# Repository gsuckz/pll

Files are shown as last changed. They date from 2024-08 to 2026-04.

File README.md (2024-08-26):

# Sintetizador de Frecuencias en banda Ku 

## Funcionamiento
    El dispositivo genera una señal en banda Ku {10,6 , 11,8} GHz. Con un paso de 1Mhz, teniendo 1200 Valores posibles. Estos se envían a través de una aplicacion de Android usando Bluetooth. También es posible realizar un barrido de frecuecnias, con un paso menor, 0,25 MHz.

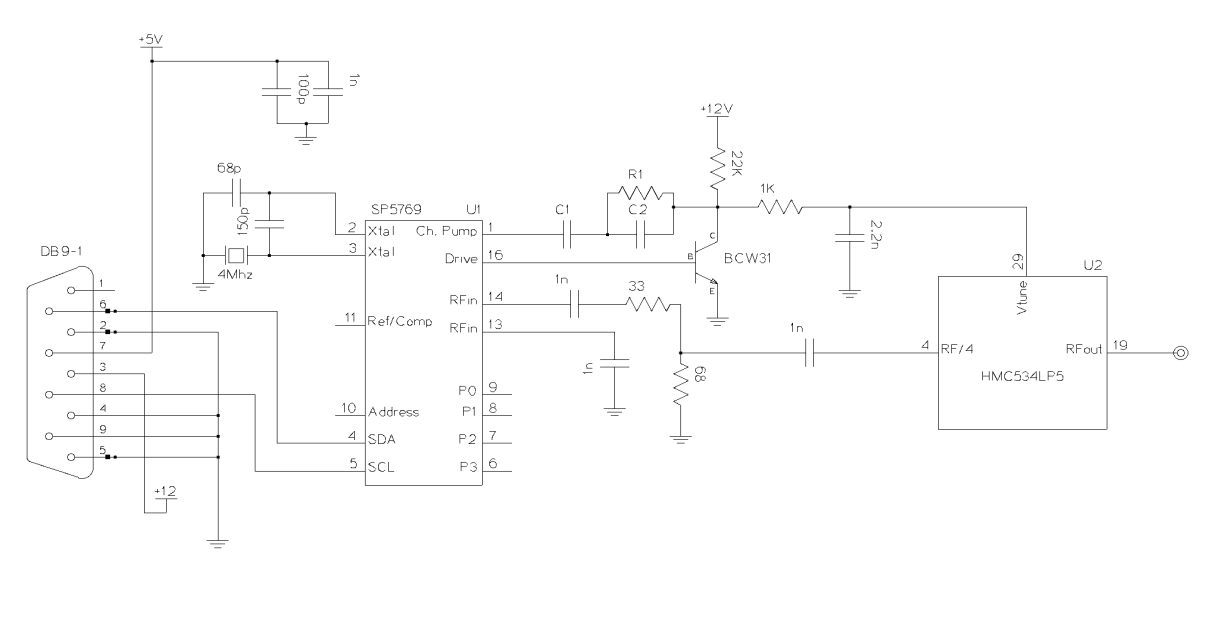
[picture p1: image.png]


Este repositorio contiene el código para controlar un Sintentizador de frecuencias Zarlink SP5769 que controla un VCO HMC534LP5.

La dirección I2C del SP5769 se selecciona con el nivel del tension aplicado a ADDRESS (%Vcc) ADDRESS = "11000101"

El ESP32 debe escribir en los registros del SP5769 los valores (a través de un bus I2C). Los registros son:
## Programmable divider: 
    Controla la razón entre la frecuencia del VCO interno y la de referencia (Un numero de 15 bit)
## Control Data: Tiene varios bits que controlan el funcionamiento (Ver datasheet para saber posicion):

    [R3:R0]: Controla el divisor de frecuencia de referencia (Ver tabla) - Ajustado al valor 64 -> 0101

    [C1:C0]: Seleccion la corriente de la bomba de carga. Ver tabla datasheet (Valor fijado por el circuito)

    RE: Enable del oscilador de ref 

    [T2:T0] = Bits de control de modo test - No se usa

    [P3:P0] = Estados del puerto de salida - No se usa

    RS: REF/COMP seleccion (Se usa alta impedancia)

Aquí se configura: Modo Test Off, Corriente de la bomba de carga Icp=+-155[µA], pin
de REF/COMP en alta impedancia, y todos los puertos, P3 a P0 a 0[V]

## Especifaciones del programa 
### Iniciar 
    El programa debe iniciar la comunicación por bluetooth y configurar el registro de control según se indica en el documento "INFORME-TRABAJO-GRADUACION-CANGEMI-JOSE-I.pdf". Luego debe esperar por cualquiera de las 2 instrucciones posibles.

### Ajuste de frecuencia
    El programa debe recibir por bluetooth el valor de la frecuncia deseada, luego debe calcular el valor del multiplicador necesario y escribirlo en los registros programmable divider.

### Barrido de frecuencia
    El programa de barrer las frecuencias sintetizables en un tiempo indicado por el usuario. Con limites Tmin y Tmax

El valor recibido es una cadena de caracteres con la frecuencia

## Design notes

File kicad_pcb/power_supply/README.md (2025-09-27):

## Datasheet Componentes
- VCO HMC534LP5: [Datasheet](https://www.analog.com/media/en/technical-documentation/data-sheets/hmc534.pdf)

- Sintetizador SP5769: [Datasheet](https://www.alldatasheet.com/datasheet-pdf/view/77217/MITEL/SP5769.html)

- Diodo Zener 1N4732A (4.7V): [Datasheet](https://www.alldatasheet.com/datasheet-pdf/view/58834/DIODES/1N4733A.html) 

- Diodo Zener BZX55C12 (12V): [Datasheet](https://www.vishay.com/docs/85604/bzx55.pdf)

- Tiristor MCR100-6 : [Dataset](https://www.alldatasheet.com/datasheet-pdf/view/888541/SEMTECH_ELEC/MCR100-6.html)

- Tiristor TYN615 (SCR): [Datasheet](https://www.alldatasheet.es/datasheet-pdf/view/25111/STMICROELECTRONICS/TYN612.html)

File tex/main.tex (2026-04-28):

% ============================================================
%  INFORME DE PRÁCTICA PROFESIONAL SUPERVISADA
%  Reparación y Rediseño de Sintetizador de Frecuencias Banda Ku
% ============================================================
\documentclass[12pt, a4paper]{article}

% --- Paquetes ---
\usepackage[spanish, es-tabla]{babel}
\usepackage[utf8]{inputenc}
\usepackage[T1]{fontenc}
\usepackage{geometry}
\geometry{top=2.5cm, bottom=2.5cm, left=3cm, right=2.5cm}

\usepackage{graphicx}
\usepackage{float}
\usepackage{booktabs}
\usepackage{array}
\usepackage{amsmath}
\usepackage{amssymb}
\usepackage{hyperref}
\usepackage{fancyhdr}
\usepackage{titlesec}
\usepackage{setspace}
\usepackage{parskip}
\usepackage{caption}
\usepackage{subcaption}
\usepackage{xcolor}
\usepackage{tcolorbox}
\usepackage{enumitem}
\usepackage{listings}
\usepackage{microtype}
\usepackage{lmodern}
\usepackage{pdfpages}

% --- Color institucional ---
\definecolor{azulUNT}{RGB}{0, 51, 102}
\definecolor{grisClaro}{RGB}{230, 230, 230}
% --- Encabezado y pie de página ---
\pagestyle{fancy}
\fancyhf{}
\fancyhead[L]{\small\textcolor{azulUNT}{PPS – Sintetizador de Frecuencias Banda Ku}}
\fancyhead[R]{\small\textcolor{azulUNT}{UNT – FCEyT}}
\fancyfoot[C]{\thepage}
\renewcommand{\headrulewidth}{0.4pt}

% --- Formato de títulos ---
\titleformat{\section}
{\large\bfseries\color{azulUNT}}
{\thesection.}{0.5em}{}[\titlerule]

\titleformat{\subsection}
{\normalsize\bfseries\color{azulUNT}}
{\thesubsection}{0.5em}{}

\titleformat{\subsubsection}
{\normalsize\itshape\bfseries}
{\thesubsubsection}{0.5em}{}

% --- Listings (código) ---
\lstset{
	basicstyle=\ttfamily\small,
	keywordstyle=\color{azulUNT}\bfseries,
	commentstyle=\color{gray}\itshape,
	stringstyle=\color{red!60!black},
	numbers=left,
	numberstyle=\tiny\color{gray},
	frame=single,
	breaklines=true,
	captionpos=b,
	language=C++
}

% --- Interlineado ---
\setstretch{1.15}

% ============================================================
\begin{document}
	
	% ============================================================
	%  PORTADA
	% ============================================================
	\thispagestyle{empty}
	\begin{titlepage}
		\centering
		\vspace*{0.5cm}
		
		{\Large \textbf{Universidad Nacional de Tucumán}}\\[0.3cm]
		{\large Facultad de Ciencias Exactas y Tecnología}\\[0.2cm]
		{\large Carrera: Ingeniería en Electrónica}\\[2cm]
		
		\noindent\rule{\textwidth}{1.5pt}\\[0.4cm]
		{\LARGE \textbf{Reparación y Rediseño de un\\[0.2cm]
				Sintetizador de Frecuencias en Banda Ku}}\\[0.3cm]
		\noindent\rule{\textwidth}{1.5pt}\\[1.5cm]
		
		{\large \textbf{Informe de Práctica Profesional Supervisada}}\\[2cm]
		
		\begin{minipage}[t]{0.48\textwidth}
			\raggedright
			\textbf{Autor:}\\
			Alexis Vale
			Jesús Avila
		\end{minipage}
		\hfill
		\begin{minipage}[t]{0.48\textwidth}
			\raggedleft
			\textbf{Directores:}\\
			Fernando Miranda Bonomi\\
			Juan Ise
		\end{minipage}\\[2cm]
		
		\textbf{Lugar de realización:}\\
		Laboratorio de Telecomunicaciones – FaCET – UNT\\[1cm]
		
		\textbf{Período:} 2025–2026\\[2cm]
		
		\vfill
		{\small Tucumán, Argentina}
	\end{titlepage}
	
	% ============================================================
	%  RESUMEN
	% ============================================================
	\newpage
	\thispagestyle{plain}
	\section*{Resumen}
	\addcontentsline{toc}{section}{Resumen}
	
	El presente informe describe el proceso de recuperación y rediseño integral de un sintetizador de
	frecuencias para microondas diseñado para operar en la banda Ku (10{,}6~GHz a 11{,}8~GHz),
	originalmente desarrollado en 2009 y recibido en estado no funcional. El trabajo abarcó el diagnóstico
	del hardware heredado, la identificación de fallas críticas en el oscilador controlado por tensión (VCO),
	el reemplazo de componentes dañados y, finalmente, el rediseño completo del circuito impreso (PCB)
	ante la degradación acumulada por múltiples intervenciones previas.
	
	Como parte del rediseño, el controlador original (microcontrolador PIC) fue reemplazado por una
	plataforma ESP32, incorporando comunicación Bluetooth e interfaz de usuario. La validación funcional
	se realizó en el banco de microondas del Laboratorio de Telecomunicaciones, confirmando el
	enclavamiento del lazo PLL con un error relativo menor al 0{,}15\% a lo largo de toda la banda operativa.
	
	\bigskip
	\noindent\textbf{Palabras clave:} sintetizador de frecuencias, banda Ku, PLL, VCO, ESP32, microondas, rediseño PCB.
	
	% ============================================================
	%  ÍNDICE
	% ============================================================
	\newpage
	\tableofcontents
	\newpage
	
	% ============================================================
	%  1. INTRODUCCIÓN
	% ============================================================
	\section{Introducción}
	
	\subsection{Contexto del sistema}
	
	El equipo objeto del presente trabajo es un sintetizador de frecuencias para microondas diseñado para
	operar en la banda Ku. Fue desarrollado originalmente en el año 2009 y basa su funcionamiento en un
	lazo de seguimiento de fase (\textit{Phase-Locked Loop}, PLL), compuesto por un oscilador controlado
	por tensión (VCO HMC534LP5) y un sintetizador de frecuencias integrado (SP\,5769), controlado
	mediante bus I2C.
	
	El equipo fue recibido en estado completamente no funcional: presentaba ausencia total de la etapa de
	alimentación y daños severos en el módulo de control e interfaz (la placa donde residía el
	microcontrolador encargado de la selección de frecuencia). Adicionalmente, la inspección de la placa
	principal de RF reveló indicios de intentos de reparación previos no documentados: pistas de cobre
	recubiertas con estaño, cortes en el ruteo original y puentes improvisados para restituir continuidad
	eléctrica. Este nivel de deterioro comprometía severamente la integridad de las señales de alta frecuencia.
	
	\subsection{Aplicación}
	
	El propósito del proyecto es el reacondicionamiento integral del equipo para incorporarlo como
	instrumento de trabajo en el Laboratorio de Telecomunicaciones de la Facultad de Ciencias Exactas y
	Tecnología de la Universidad Nacional de Tucumán. El sistema restaurado tendrá un fin estrictamente
	educativo y didáctico, permitiendo a los estudiantes de futuras cursadas y proyectos de investigación
	realizar prácticas reales con señales de microondas, facilitando la comprensión práctica de conceptos
	avanzados de RF y lazos de seguimiento de fase (PLL).
	
	\subsection{Objetivo del trabajo}
	
	El objetivo principal es recuperar la operatividad total del sintetizador de microondas. Debido a las fallas
	acumuladas por deterioro del hardware, la obsolescencia técnica de su implementación física y los
	intentos de reparación previos infructuosos, el trabajo no se limita a una reparación puntual: requiere
	un \textbf{rediseño integral de la PCB} para garantizar la estabilidad del sistema, minimizar pérdidas y
	asegurar su funcionamiento a largo plazo.
	
	\subsection{Alcance}
	
	Para cumplir con los objetivos planteados, el proyecto abarca las siguientes etapas:
	
	\begin{enumerate}[leftmargin=*, label=\textbf{\arabic*.}]
		\item \textbf{Diagnóstico:} Relevamiento detallado del estado actual de los componentes heredados y
		análisis crítico del circuito original.
		\item \textbf{Reparación inicial:} Pruebas de supervivencia de los componentes críticos (VCO y
		sintetizador) y montaje de una alimentación provisoria.
		\item \textbf{Rediseño de PCB:} Migración del diseño esquemático y desarrollo de una nueva placa de
		circuito impreso (mediante KiCad y AWR), solucionando los problemas de ruteo e integridad de
		señal de la versión anterior.
		\item \textbf{Validación funcional:} Mediciones en banco de microondas para asegurar el enclavamiento
		en frecuencia y la potencia de salida esperada.
	\end{enumerate}
	
	% ============================================================
	%  2. DESCRIPCIÓN DEL SISTEMA ORIGINAL
	% ============================================================
	\section{Descripción del sistema original}
	
	\subsection{Arquitectura general}
	
	El sintetizador opera bajo el principio de síntesis directa mediante lazo de seguimiento de fase (PLL).
	Los componentes principales del sistema heredado son:
	
	\begin{itemize}[leftmargin=*]
		\item \textbf{Sintetizador/PLL:} SP\,5769 (Phillips/NXP), controlado por bus I2C.
		\item \textbf{Oscilador controlado por tensión (VCO):} HMC534LP5 (Analog Devices/Hittite),
		encapsulado QFN de 5$\times$5\,mm.
		\item \textbf{Controlador original:} Microcontrolador PIC16F873A, encargado de la programación de
		registros del PLL.
		\item \textbf{Transistor externo:} BCW\,31 en configuración amplificador inversor, para adaptar la
		tensión de sintonía (\textit{Vtune}) requerida por el VCO (0–13\,V) desde la salida de 5\,V del
		sintetizador.
	\end{itemize}
	
\begin{figure}[H]
	\centering
	\fcolorbox{azulUNT}{white}{
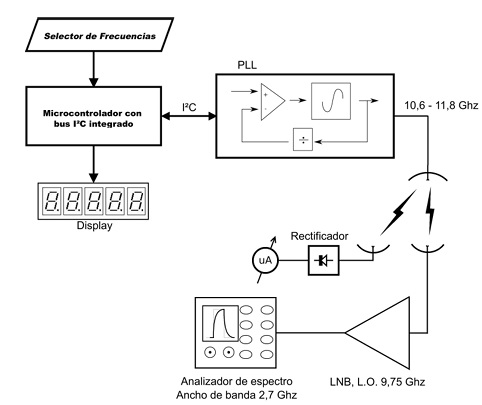
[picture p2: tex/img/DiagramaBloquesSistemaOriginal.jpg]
		
	}
	\caption{Diagrama en bloques del sistema original.}
	\label{fig:bloques_original}
\end{figure}
	
	\subsection{Funcionamiento}
	
	\subsubsection{Generación de frecuencia}
	El VCO genera una señal de RF cuya frecuencia depende de la tensión aplicada en su pin de sintonía
	(\textit{Vtune}). El sintetizador SP\,5769 implementa el lazo PLL: divide la señal de salida del VCO
	mediante divisores programables, la compara con una referencia interna de cristal y genera una señal
	de error (bomba de carga) que, a través del amplificador externo con el BCW\,31, ajusta \textit{Vtune}
	hasta que la frecuencia de salida coincide con la programada.
	
	\subsubsection{Control e interfaz}
	El PIC16F873A (en el diseño original) programa los registros internos del SP\,5769 vía bus I2C,
	estableciendo los valores de los divisores de frecuencia que determinan la frecuencia de síntesis.
	
	\subsubsection{Rango de salida RF}
	El sistema está diseñado para operar en el rango de \textbf{10{,}6\,GHz a 11{,}8\,GHz}, cubriendo la
	banda Ku de interés.
	
	\subsection{Limitaciones detectadas}
	
	\begin{itemize}[leftmargin=*]
		\item \textbf{Dependencia del SP\,5769:} Al tratarse de un componente específico ya presente en la
		placa original, su disponibilidad en el mercado actual es limitada. Durante el proyecto, el
		SP\,5769 original resultó dañado, requiriéndose la adquisición de uno nuevo con distinto
		encapsulado, lo que obligó a adaptar la huella en la PCB rediseñada.
		\item \textbf{Dificultad de mantenimiento:} Las múltiples reparaciones sucesivas sobre la placa
		original fueron degradando progresivamente las soldaduras y la integridad física de los
		componentes, haciendo inevitables el rediseño completo de la PCB y el reemplazo con
		componentes nuevos.
		\item \textbf{Encapsulado QFN del VCO:} El HMC534LP5 carece de pines expuestos tradicionales,
		concentrando su disipación térmica en la almohadilla central inferior. Esto hace que su soldadura
		y reemplazo sean técnicamente exigentes y requieran equipamiento especializado.
		\item \textbf{El microcontrolador usado es muy antiguo} Se decidipo cambiar por un ESP32 por su menor precio, ensamblado comodo en pcb, posibilidad de programar en C/Arduino y su conexión Bluetooth.
	\end{itemize}
	
	% ============================================================
	%  3. DIAGNÓSTICO Y FALLA
	% ============================================================
	\section{Diagnóstico y falla}
	
	\subsection{Análisis inicial e implementación de hardware de prueba}
	
	El proceso de diagnóstico comenzó con el estudio de las hojas de datos (\textit{datasheets}) de los
	componentes críticos: el sintetizador SP\,5769 y el VCO HMC534LP5. Se determinaron los niveles de
	tensión necesarios para la operación y se realizó una inspección visual del conexionado.
	
	Dado que el sistema se recibió sin su etapa de alimentación original, fue necesario utilizar hardware
	auxiliar:
	
	\begin{itemize}[leftmargin=*]
		\item \textbf{Alimentación de 12\,V:} Se diseñó y fabricó una fuente regulable de 12\,V utilizando el método de transferencia térmica (planchado) para la creación de la placa de circuito impreso (PCB).
		\item \textbf{Alimentación de 5\,V:} Para la lógica de control, se utilizó directamente la salida regulada de 5\,V provista por la placa de desarrollo ESP32.
		\item \textbf{Interfaz de conexión (Shield ESP32):} Se fabricó una placa adaptadora (tipo \textit{poncho} o \textit{shield}), también mediante el método de transferencia térmica, para interconectar de manera segura la ESP32 con la placa de RF heredada.
	\end{itemize}

	\begin{figure}[H]
		\centering
		\begin{subfigure}{0.45\textwidth}
			\centering
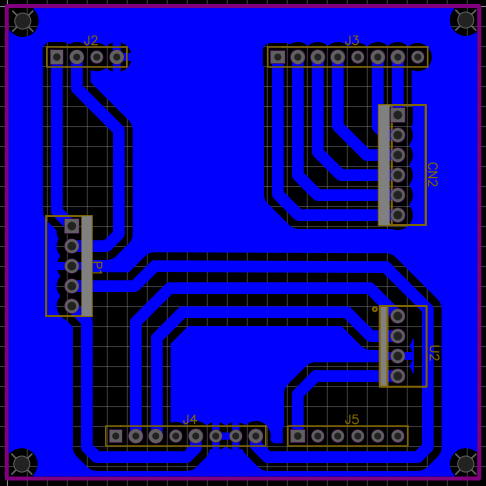
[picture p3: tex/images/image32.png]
			
			\caption{Vista superior}
		\end{subfigure}
		\hfill
		\begin{subfigure}{0.45\textwidth}
			\centering
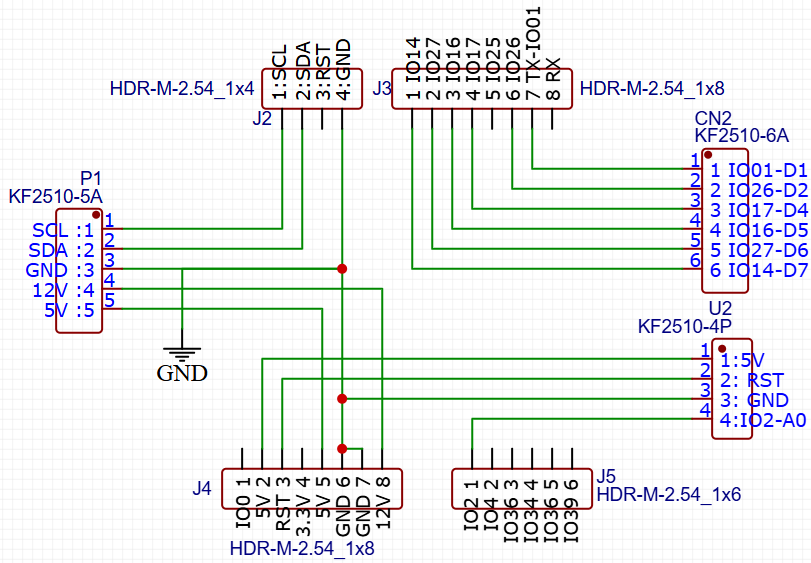
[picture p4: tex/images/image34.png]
			
			\caption{Vista inferior}
		\end{subfigure}
		\caption{Shield ESP32 implementado provisionalmente.}
		\label{fig:shield_esp32}
	\end{figure}
	
	\subsection{Desarrollo de firmware}
	
	El código fuente original (desarrollado para PIC16F873A) resultó de difícil comprensión y adaptación.
	Se decidió descartar el firmware existente y desarrollar uno nuevo desde cero sobre la plataforma
	ESP32, basándose estrictamente en los registros y diagramas de tiempos especificados en la hoja de
	datos del SP\,5769. El repositorio del nuevo firmware se encuentra disponible en:
	\url{https://github.com/gsuckz/pll} 
	
	Tras múltiples pruebas y ajustes de sincronización, se logró establecer comunicación exitosa a través
	del bus I2C entre la ESP32 y el SP\,5769, confirmando que la lógica digital del sintetizador se
	encontraba operativa. Se detectó y corrigió además un error en los valores asignados a uno de los
	divisores programables.
	
	\subsection{Falla principal: daño en el VCO}
	
	\subsubsection{Síntomas observados}
	El día 29 de agosto de 2024 se realizaron las primeras pruebas formales sobre el banco de microondas
	(ver Informe de Actividades de Laboratorio adjunto en Anexo). Los síntomas observados fueron:
	
	\begin{itemize}[leftmargin=*]
		\item Ausencia total de potencia de salida de RF, confirmada con sensor rectificador con medidor
		analógico y con analizador de RF digital.
		\item El PLL no lograba el enclavamiento (\textit{no lock}) a pesar de que el SP\,5769 respondía
		correctamente a los comandos I2C y permitía fijar la frecuencia programada.
		\item Al analizar el lazo cerrado, el sintetizador intentaba ajustar \textit{Vtune} para corregir la
		frecuencia, pero no recibía señal de realimentación (\textit{feedback}) por parte del VCO.
	\end{itemize}
	
	\subsubsection{Diagnóstico conclusivo}
	Descartados errores en el código (corregidos previamente), en el conexionado y en los niveles de
	alimentación, se concluyó que el VCO HMC534LP5 estaba \textbf{dañado irreversiblemente de forma
		previa} a la recepción del equipo.
	
	\subsection{Reemplazo del VCO (encapsulado QFN)}
	
	La confirmación de la falla del VCO obligó a su reemplazo, lo cual representó un desafío técnico
	significativo debido al encapsulado QFN de 5$\times$5\,mm: carece de pines expuestos y concentra su
	disipación térmica en la almohadilla central inferior. Se aplicaron técnicas de soldadura térmica
	adecuadas para este tipo de empaquetado, logrando extraer el componente dañado y montar
	exitosamente la unidad de reemplazo. Para este procedimiento fue necesario recurrir a la asistencia
	técnica de \textbf{DIGICOM}, dado que el proceso requería equipamiento especializado.
	
	\subsection{Problemas de alimentación y reestructuración}
	
	Tras la instalación del nuevo VCO, el sistema mostraba actividad pero no lograba enclavarse. Se
	detectó que el regulador interno de la ESP32 no poseía la capacidad de corriente suficiente para
	alimentar simultáneamente la lógica digital, el sintetizador y el VCO. La caída en la línea de 5\,V
	(por debajo de 4{,}5\,V) desestabilizaba por completo el lazo de sintonía.
	
	Se reestructuró la arquitectura de alimentación:
	
	\begin{itemize}[leftmargin=*]
		\item \textbf{Separación de fuentes:} Se incorporó una fuente conmutada (\textit{switching}) dedicada
		exclusivamente a proveer los 5\,V robustos que demandan los componentes de RF (VCO y
		sintetizador), con masa común a la etapa de control digital (ESP32).
		\item \textbf{Gestión de Vtune:} Se verificó el correcto funcionamiento del amplificador inversor
		discreto (BCW\,31), alimentado por la línea de 12\,V y comandado por la salida \textit{Drive}
		del SP\,5769, encargado de proveer la amplitud de tensión necesaria (0–13\,V) para el control
		del VCO.
	\end{itemize}
	
	Adicionalmente, se identificó el ventilador (\textit{cooler}) acoplado al disipador térmico del VCO
	como posible fuente de ruido. De manera preventiva, se diseñó e implementó un filtro activo pasa-bajos
	compuesto por un transistor NPN 2N2222 en configuración emisor seguidor, una resistencia de base de
	33\,k$\Omega$ y un capacitor de 10\,\textmu F, logrando desacoplar la línea de alimentación de RF
	de las posibles interferencias.
	
	\subsection{Falla y obsolescencia definitiva del hardware heredado}
	
	Tras múltiples intervenciones sobre la PCB original, la placa acumuló un deterioro físico significativo.
	El reemplazo del VCO original, que se encontraba dañado, implicó varias operaciones de desoldado y
	resoldado que degradaron las pistas y almohadillas. Durante estas tareas, un segundo VCO también
	resultó dañado debido a un error de manipulación, lo que agravó el estado general del circuito impreso.
	
	Como consecuencia de estas intervenciones sucesivas, la integridad mecánica y eléctrica de la PCB se
	vio comprometida, volviendo poco confiable su reutilización. En este contexto, se tomó la decisión de
	diseñar una nueva placa, no solo para recuperar la funcionalidad sino también para introducir mejoras
	constructivas, como el reemplazo del puerto RS232 por conectores tipo peine que facilitan la
	interconexión y el mantenimiento.
	
	Durante la etapa de puesta en marcha del nuevo hardware, se detectó la ausencia de respuesta del
	PLL SP5769 a través de la interfaz I2C. Tras las
	verificaciones correspondientes, se concluyó que el dispositivo se encontraba dañado. Dado que no fue
	posible conseguir el mismo componente en el encapsulado original, se optó por adquirir una variante
	disponible en el mercado con distinto encapsulado (se adquirió por error un chip en formato SSOP 16 en lugar del original SOP), lo que requirió una nueva iteración del diseño de la
	PCB para adaptar la huella al formato SSOP 16.
	
	De este modo, el proceso de rediseño no solo respondió al deterioro físico de la placa original, sino
	también a la necesidad de adaptación frente a la disponibilidad de componentes, consolidando una
	solución funcional sobre una nueva plataforma de hardware.
	% ============================================================
	%  4. REDISEÑO DEL SISTEMA
	% ============================================================
	\section{Rediseño del sistema}
	
	\subsection{Motivaciones}
	
	Las principales razones que llevaron al rediseño completo fueron:
	
	\begin{enumerate}[leftmargin=*, label=\textbf{\arabic*.}]
		\item Daño físico acumulado en la PCB original por múltiples reparaciones sucesivas.
		\item Pérdida del SP\,5769 original y necesidad de adaptación al nuevo encapsulado disponible en
		el mercado.
		\item Garantizar la integridad de señal en alta frecuencia (banda Ku), imposible de asegurar sobre
		una placa con pistas dañadas y puentes improvisados.
		\item Facilitar el mantenimiento y la reproducibilidad del equipo para uso educativo a largo plazo.
	\end{enumerate}
	
	\subsection{Cambios principales respecto al diseño original}
	
	\begin{table}[H]
		\centering
		\caption{Comparación entre el sistema original y el rediseñado.}
		\label{tab:comparacion}
		\renewcommand{\arraystretch}{1.3}
		\begin{tabular}{>{\bfseries}p{4cm} p{5cm} p{5cm}}
			\toprule
			\textbf{Aspecto} & \textbf{Sistema original} & \textbf{Sistema rediseñado} \\
			\midrule
			Controlador        & PIC16F873A                     & ESP32 \\
			Interfaz de usuario & Sin interfaz Bluetooth        & Bluetooth (app móvil / terminal) \\
			PCB                & Placa heredada (2009), dañada  & PCB rediseñada en KiCad \\
			Encapsulado PLL    & SP\,5769 (encapsulado original) & SP\,5769 (nuevo encapsulado, huella adaptada) \\
			Arquitectura RF    & PLL + VCO externo              & PLL + VCO externo (sin cambios) \\
			Firmware           & Código PIC (código fuente inaccesible) & Firmware nuevo en ESP32 (repositorio abierto) \\
			Alimentación       & Fuente interna (original perdida) & Fuente switching dedicada para RF + 5\,V lógica \\
			\bottomrule
		\end{tabular}
	\end{table}
	
	\subsection{Cambio de plataforma de control}
	
	\subsubsection{Sistema original: PIC16F873A}
	El microcontrolador PIC16F873A ejercía un control básico del PLL: programaba los divisores de
	frecuencia del SP\,5769 mediante I2C a partir de una selección fija de frecuencias.
	
	\subsubsection{Sistema rediseñado: ESP32}
	La plataforma ESP32 ofrece significativas mejoras:
	
	\begin{itemize}[leftmargin=*]
		\item \textbf{Configuración del PLL vía I2C:} Manteniendo compatibilidad total con el SP\,5769.
		\item \textbf{Interfaz Bluetooth:} Permite configurar la frecuencia de síntesis de forma inalámbrica
		desde una aplicación de terminal Bluetooth en dispositivo móvil o PC.
		\item \textbf{Visualización en pantalla:} Una pantalla lcs 16x2 con teclado
		\item \textbf{Mayor flexibilidad:} El firmware puede actualizarse fácilmente; el repositorio es abierto
		y documentado.
	\end{itemize}
	
	\subsubsection{Justificación de la decisión}
	La migración a ESP32 se justifica por la mejora sustancial en usabilidad (interfaz Bluetooth elimina la
	necesidad de conexión física para operar el equipo), la mayor flexibilidad de control y programación,
	y la disponibilidad inmediata del hardware en el contexto del laboratorio.
	
	\subsection{Decisiones de diseño relevantes}
	
	\begin{tcolorbox}[colback=grisClaro, colframe=azulUNT, title=\textbf{Resumen de decisiones de diseño}]
		\begin{itemize}[leftmargin=*]
			\item \textbf{Mantener:} Arquitectura PLL + VCO externo, sintetizador SP\,5769, VCO HMC534LP5.
			\item \textbf{Cambiar:} Plataforma de control (PIC $\rightarrow$ ESP32), PCB completa (rediseño en
			KiCad), encapsulado del SP\,5769 (adaptación de huella).
			\item \textbf{Incorporar:} Fuente switching dedicada para RF, filtro activo en \textit{Vtune},
			firmware abierto y documentado, interfaz Bluetooth.
		\end{itemize}
	\end{tcolorbox}
	
	% ============================================================
	%  5. IMPLEMENTACIÓN
	% ============================================================
	\section{Implementación}
	
	\subsection{Diseño de PCB}
	
	\subsubsection{Consideraciones de alta frecuencia}
	El diseño de la nueva PCB debió contemplar las exigencias propias de los circuitos operando en la
	banda Ku:
	
	\begin{itemize}[leftmargin=*]
		\item \textbf{Integridad de señal RF:} Las líneas de transmisión de RF se diseñaron como
		\textit{striplines} con impedancia característica controlada de 50\,$\Omega$.
		\item \textbf{Cálculo de dimensiones:} Se utilizó el software \textbf{AWR Microwave Office} para
		determinar los anchos de pista y separaciones necesarios para lograr la adaptación de impedancias
		en las frecuencias de trabajo (banda Ku).
		\item \textbf{Software EDA:} El ruteo y el diseño del layout se realizaron en \textbf{KiCad}.
		\item \textbf{Adaptación de huella:} El nuevo encapsulado del SP\,5769 adquirido difería del
		original, por lo que se generó una nueva huella (\textit{footprint}) adaptada en KiCad.
	\end{itemize}
	
\begin{figure}[H]
	\centering
	\fcolorbox{azulUNT}{white}{
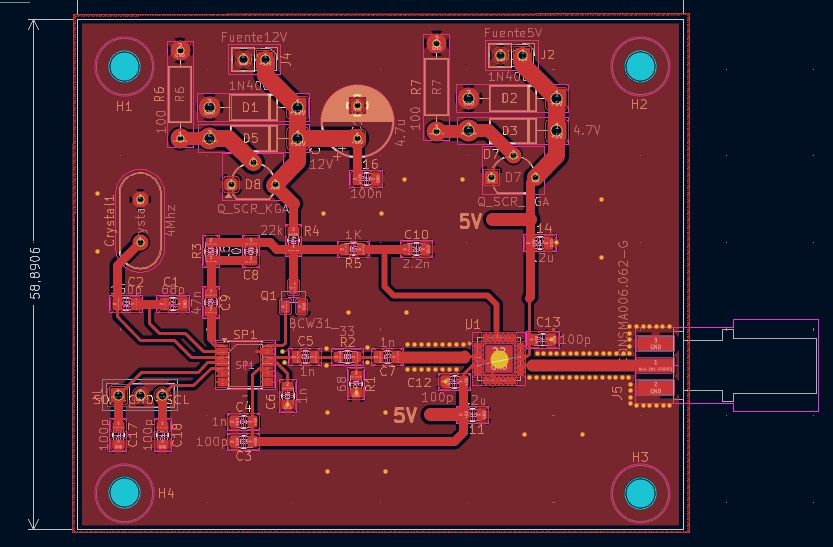
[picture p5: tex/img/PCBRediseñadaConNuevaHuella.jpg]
		
	}
	\caption{Layout de la PCB rediseñada. Usando la huella SSOP 16}
	\label{fig:bloques_original}
\end{figure}
	
	\subsection{Montaje e integración}
	
	\begin{itemize}[leftmargin=*]
		\item Soldadura de componentes SMD, incluyendo el VCO HMC534LP5 (QFN 5$\times$5\,mm) y el
		nuevo SP\,5769 con encapsulado adaptado.
		\item Programación inicial del ESP32 con el nuevo firmware.
		\item Integración mecánica: se diseñó y fabricó mediante \textbf{impresión 3D} un gabinete a medida
		para alojar el sistema completo y proteger las conexiones.
	\end{itemize}

	% ============================================================
	%  6. VALIDACIÓN
	% ============================================================
	\section{Validación funcional}
	
	\subsection{Metodología de medición}
	
	Las mediciones de validación se realizaron en el \textbf{banco de microondas} del Laboratorio de
	Telecomunicaciones de la FCEyT–UNT. Para determinar la frecuencia real emitida ($f_0$), se midió la
	longitud de onda dentro de la guía de onda ($\lambda_g$) utilizando el \textbf{ondámetro de ranura
		resonante}. Conociendo la dimensión transversal de la guía utilizada ($2a = 45{,}72$\,mm, que define
	la longitud de onda de corte $\lambda_c$), se calculó la longitud de onda en el espacio libre ($\lambda_0$)
	mediante la relación:
	
	\begin{equation}
		\frac{1}{\lambda_0^2} = \frac{1}{\lambda_g^2} + \frac{1}{\lambda_c^2}
		\label{eq:lambda}
	\end{equation}
	
	Finalmente, la frecuencia de oscilación se obtuvo como $f_0 = c / \lambda_0$, donde $c$ es la velocidad
	de la luz en el vacío.
	
	\subsection{Ensayos realizados}
	
	\subsubsection{Prueba de límites físicos del VCO (bomba de carga)}
	
	Para verificar la excursión máxima del VCO instalado, se forzaron por software los estados extremos
	de la bomba de carga del SP\,5769:
	
	\begin{itemize}[leftmargin=*]
		\item \textbf{CP-Disable (límite inferior):} Con la bomba de carga deshabilitada, la tensión de
		sintonía cae al mínimo. Se midió $\lambda_g = 42{,}52$\,mm, obteniendo una frecuencia límite
		inferior de $f_{min} \approx 9{,}3$\,GHz.
		\item \textbf{CP-Sink (límite superior):} Con la bomba de carga forzada a drenar corriente máxima,
		la tensión alcanza el límite superior. Se midió $\lambda_g = 29{,}12$\,mm, obteniendo una
		frecuencia límite superior de $f_{max} \approx 12{,}21$\,GHz.
	\end{itemize}
	
	Estos resultados confirman que el hardware supera holgadamente el rango requerido (10{,}6–11{,}8\,GHz).
	
	\subsubsection{Validación del enclavamiento de frecuencia}
	
	Se realizó un barrido discreto programando el sintetizador en saltos de 300\,MHz a lo largo de la banda
	de trabajo. La Tabla~\ref{tab:resultados} muestra los resultados comparativos entre la frecuencia
	programada ($f_{prog}$) y la frecuencia medida ($f_{med}$).
	
	\begin{table}[H]
		\centering
		\caption{Resultados de validación del enclavamiento PLL.}
		\label{tab:resultados}
		\renewcommand{\arraystretch}{1.3}
		\begin{tabular}{cccc}
			\toprule
			$f_{prog}$ (GHz) & $\lambda_g$ medida (mm) & $f_{med}$ (GHz) & Error relativo (\%) \\
			\midrule
			10{,}600 & 35{,}94 & 10{,}608 & 0{,}075 \\
			10{,}900 & 34{,}41 & 10{,}911 & 0{,}101 \\
			11{,}200 & 33{,}00 & 11{,}210 & 0{,}089 \\
			11{,}500 & 31{,}69 & 11{,}518 & 0{,}157 \\
			11{,}800 & 30{,}52 & 11{,}818 & 0{,}153 \\
			\bottomrule
		\end{tabular}
	\end{table}
	
	\subsubsection{Barrido de frecuencia (\textit{frequency sweep})}
	
	Se implementó y ensayó por software la función de barrido de frecuencia, verificando que el sistema
	puede recorrer toda la banda operativa de forma continua y estable.
	
	\subsection{Resultados}
	
	\begin{tcolorbox}[colback=grisClaro, colframe=azulUNT, title=\textbf{Síntesis de resultados}]
		\begin{itemize}[leftmargin=*]
			\item El PLL logró enclavamiento (\textit{lock}) en todos los puntos de frecuencia ensayados.
			\item El error relativo máximo observado fue del \textbf{0{,}157\%}, considerado despreciable para
			la aplicación educativa prevista.
			\item El VCO cubre con holgura el rango Ku requerido: desde 9{,}3\,GHz hasta 12{,}21\,GHz.
			\item El sistema operó de forma estable a lo largo de toda la banda 10{,}6–11{,}8\,GHz.
		\end{itemize}
	\end{tcolorbox}
	
	\subsection{Hardware principal y transmisión de la señal}
	
	El sistema se centra en la generación, transmisión y recepción de ondas electromagnéticas en el rango de las microondas (banda Ku). El núcleo de emisión es el sintetizador operando en un rango de 10{,}6\,GHz a 11{,}8\,GHz. Para acondicionar y caracterizar la señal, el banco cuenta con atenuadores de baja precisión (hasta 20\,dB) y de alta precisión (ajuste micrométrico de 0{,}01\,mm), además de un ondámetro de cavidad resonante.
	
	\begin{figure}[H]
		\centering
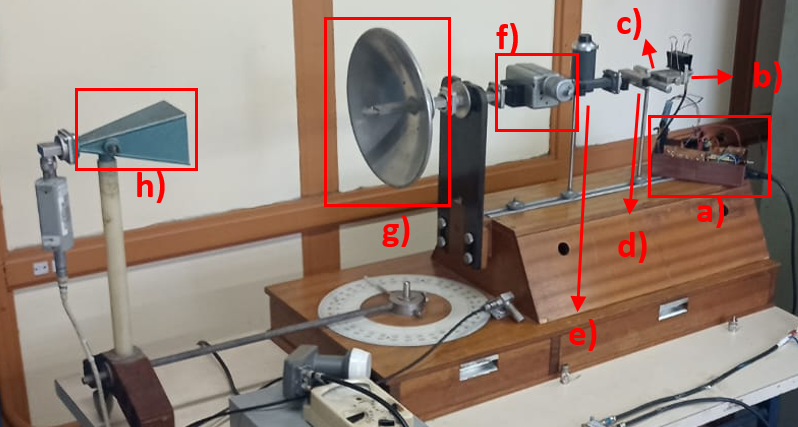
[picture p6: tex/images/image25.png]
		
		\caption{Configuración del banco de microondas.}
		\label{fig:banco_original}
	\end{figure}

	La onda viaja por la guía hasta la antena transmisora, la cual está conformada por un dipolo y un reflector parabólico que irradia con una polarización lineal vertical. En el extremo receptor, el campo es captado por una antena tipo bocina piramidal (\textit{Horn}). Para cuantificar la energía recibida, la antena se acopla a un diodo rápido Schottky montado en posición vertical, el cual rectifica la señal de RF para ser leída por un amperímetro analógico.

	\begin{figure}[H]
		\centering
		\begin{subfigure}{0.35\textwidth}
			\centering
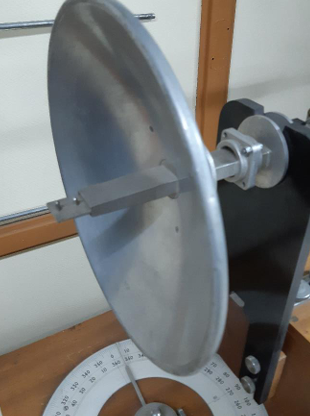
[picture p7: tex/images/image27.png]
			
			\caption{Transmisor parabólico}
		\end{subfigure}
		\hfill
		\begin{subfigure}{0.35\textwidth}
			\centering
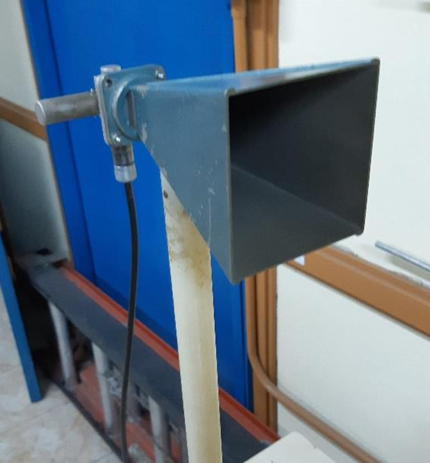
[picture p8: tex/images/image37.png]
			
			\caption{Receptor de bocina}
		\end{subfigure}
		\caption{Antenas de transmisión y recepción en el banco.}
		\label{fig:antenas_banco}
	\end{figure}
	
	\subsection{Mediciones adicionales en banco con LNB}

	Como actividad extra, se integró en la recepción un LNB (\textit{Low Noise Block}) dual para bajar en frecuencia la señal de la banda Ku y permitir su análisis con un analizador de espectro de menor rango.
	Este dispositivo capta las frecuencias y las amplifica con bajo ruido, realizando una conversión a frecuencia intermedia (IF) mediante un oscilador local (OL).

	\begin{figure}[H]
		\centering
		\begin{subfigure}{0.65\textwidth}
			\centering
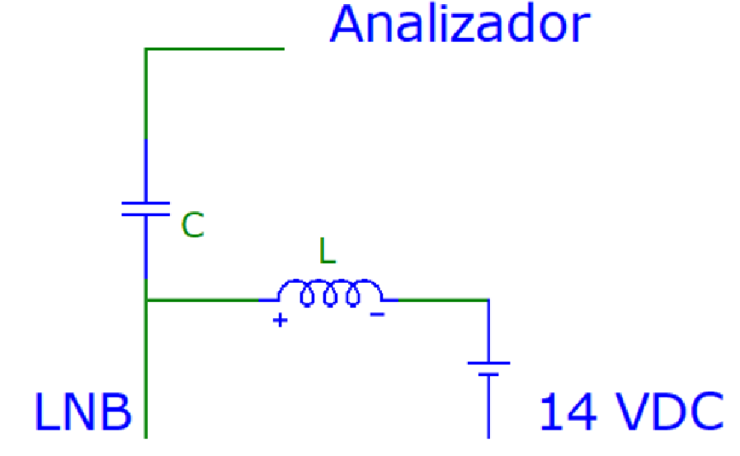
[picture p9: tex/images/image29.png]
			
			\caption{Conexión del LNB al montaje}
		\end{subfigure}
		\hfill
		\begin{subfigure}{0.3\textwidth}
			\centering
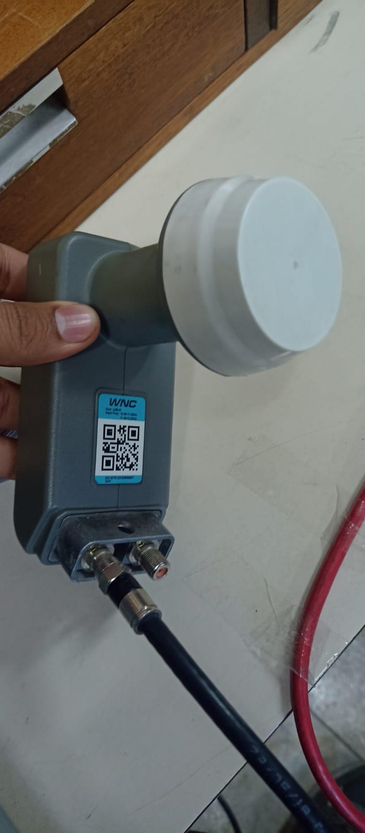
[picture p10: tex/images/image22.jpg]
			
			\caption{LNB dual}
		\end{subfigure}
		\caption{Integración de LNB en el banco experimental.}
		\label{fig:lnb}
	\end{figure}

	\paragraph{Inyector y filtro activo LC (Winegard PS-1403):}
	Para la correcta operación del LNB, se empleó un filtro inyector de continua (Winegard PS-1403) actuando como \textit{bias tee}. Esto permitió alimentar el LNB con continua sin afectar el paso de la señal de RF hacia el analizador de espectro, protegiendo sus puertos de entrada.

	\begin{figure}[H]
		\centering
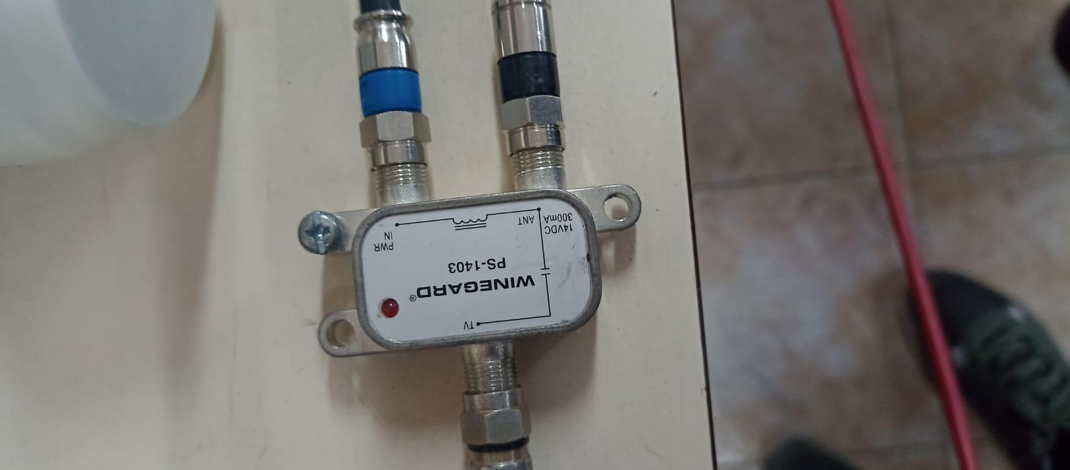
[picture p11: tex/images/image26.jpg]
		
		\caption{Filtro activo LC empleado para aislamiento y alimentación.}
		\label{fig:filtro_winegard}
	\end{figure}

	\begin{figure}[H]
		\centering
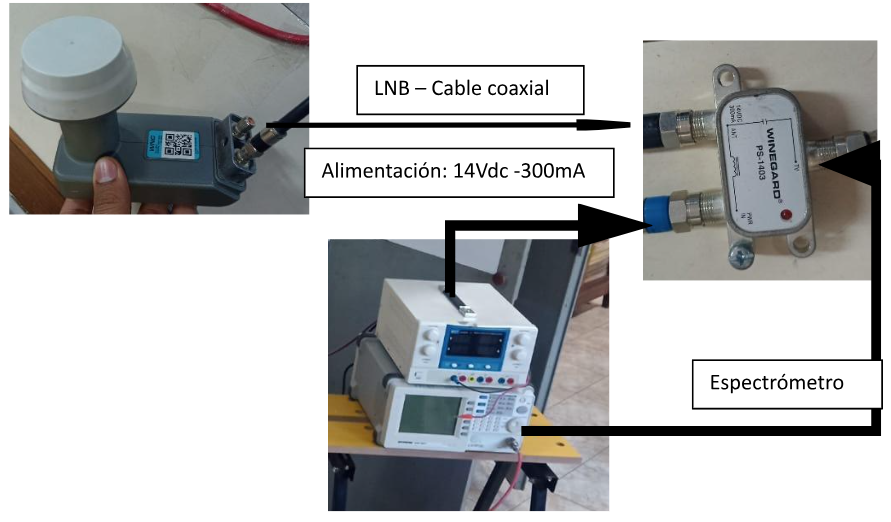
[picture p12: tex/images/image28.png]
		
		\caption{Esquema de conexiones con el analizador de espectro.}
		\label{fig:esquema_general}
	\end{figure}

	\paragraph{Lecturas de frecuencia convertida:}
	En el analizador de espectro se identificó correctamente el tono convertido a frecuencia intermedia $f_{IF} \approx 1{,}9$\,GHz.

	\begin{figure}[H]
		\centering
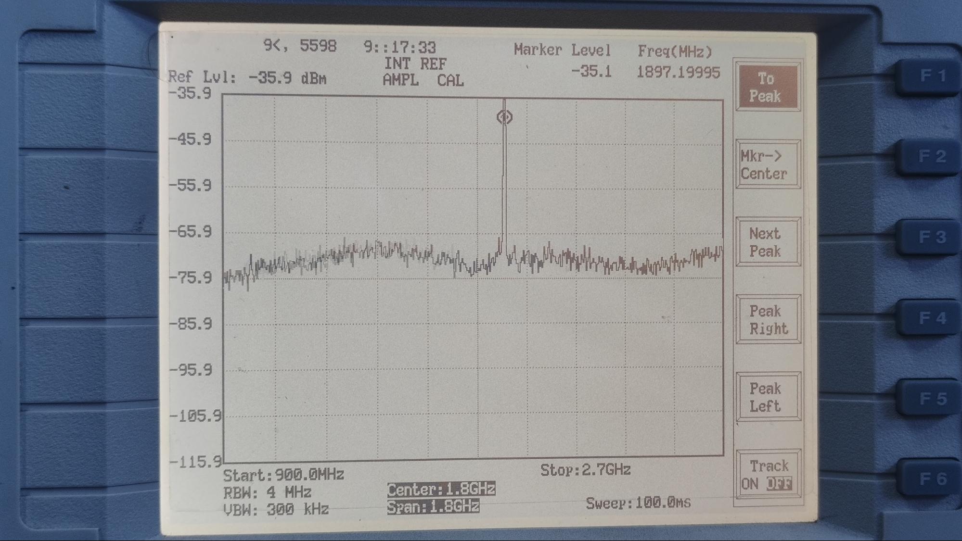
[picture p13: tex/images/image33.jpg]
		
		\caption{Tono medido en el analizador de espectro.}
		\label{fig:medicion_espectro}
	\end{figure}

	Sabiendo la frecuencia transmitida por el oscilador ($f_{RF}$) y la frecuencia detectada en el analizador ($f_{IF}$), se verifica empíricamente la frecuencia del oscilador local ($f_{OL}$) interno del LNB utilizando la relación fundamental de los mezcladores:
	\begin{equation}
		f_{OL} = f_{RF} - f_{IF} = 11{,}65\,\text{GHz} - 1{,}90\,\text{GHz} = 9{,}75\,\text{GHz}
	\end{equation}

	% ============================================================
	%  7. RESULTADOS Y CONCLUSIONES
	% ============================================================
	\section{Resultados y conclusiones}
	
	\subsection{Logros obtenidos}
	
	Se logró recuperar la funcionalidad completa del sintetizador de frecuencias en banda Ku. El sistema
	final opera correctamente en el rango 10{,}6–11{,}8\,GHz con un error de frecuencia inferior al
	0{,}16\%, confirmado mediante mediciones en banco de microondas.
	
	El rediseño integral de la PCB permitió:
	
	\begin{itemize}[leftmargin=*]
		\item Adaptar el diseño a los encapsulados de componentes actualmente disponibles en el mercado.
		\item Resolver los problemas de integridad de señal presentes en la placa heredada.
		\item Garantizar la reproducibilidad y el mantenimiento del equipo para uso educativo a largo plazo.
		\item Mejorar sustancialmente la interfaz de usuario mediante la incorporación de comunicación
		Bluetooth y una pantalla de visualización.
	\end{itemize}
	
	\subsection{Lecciones aprendidas}
	
	\begin{itemize}[leftmargin=*]
		\item La importancia del diseño de PCB orientado a la integridad de señal en alta frecuencia desde
		la etapa de concepción, para evitar problemas de reparabilidad en el futuro.
		\item La necesidad de documentar todos los intentos de reparación sobre hardware heredado para
		facilitar el diagnóstico posterior.
		\item El valor de contar con equipamiento especializado (estación de soldadura para QFN, banco de
		microondas) para proyectos de RF en banda Ku.
	\end{itemize}

	% ============================================================
	%  REFERENCIAS
	% ============================================================

	% ============================================================
	%  ANEXOS
	% ============================================================
	\newpage
	\appendix
	
	\section{Informe de actividades de laboratorio (29/08/2024)}
	\label{anx:informe_lab}

	\bigskip
	\noindent\rule{\textwidth}{0.4pt}
	
	\textbf{Fecha:} 29 de agosto de 2024\\
	\textbf{Responsable:} Jesús Avila\\
	\textbf{Proyecto:} Reparación de Sintetizador de Frecuencias\\
	\textbf{Ubicación:} Laboratorio de Telecomunicaciones
	
	\paragraph{Descripción del trabajo realizado.}
	Se realizaron tareas de diagnóstico y reparación en un sintetizador compuesto por un módulo de RF
	con sintetizador SP\,5769, VCO y placa ESP32 (interfaz Bluetooth). El firmware de la ESP32 había
	sido validado previamente (lógica mediante TDD y comunicación I2C con una BluePill programada con
	la dirección del SP\,5769).
	
	\paragraph{Procedimiento.}
	\begin{enumerate}[leftmargin=*, label=\textbf{\arabic*.}]
		\item \textbf{Conexión inicial:} Se conectó la ESP32 al módulo de RF a través del conector DB9.
		\item \textbf{Verificación de conexiones:} Con multímetro se detectó y corrigió un error en la
		referencia de conexiones.
		\item \textbf{Prueba de comunicación:} Usando la aplicación \textit{Bluetooth Terminal}, se confirmó
		que el SP\,5769 respondía correctamente, aunque no lograba el enclavamiento.
		\item \textbf{Verificación de potencia de salida:} Tanto con sensor rectificador/medidor analógico
		como con analizador de RF digital, se constató ausencia total de potencia de salida.
	\end{enumerate}
	
	\paragraph{Resultados y conclusiones.}
	La ausencia de potencia de salida y la falta de enclavamiento indicaron falla en el VCO o en el
	transistor externo. Se propuso un análisis más profundo de ambos componentes para confirmar la causa.
	
	\noindent\rule{\textwidth}{0.4pt}
-----------------------------
	\section{Configuración de registros del SP\,5769}
	\label{anx:registros}
	
\begin{table}[H]
	\centering
	\caption{Bytes en modo lectura del SP5769.}
	\label{tab:sp5769_lectura}
	\renewcommand{\arraystretch}{1.3}
	\begin{tabular}{llccccccccc}
		\toprule
		& & \multicolumn{8}{c}{\textbf{MSB $\longleftarrow$ \hspace{3cm} $\longrightarrow$ LSB}} & \\
		\midrule
		\textbf{Byte 1} & Dirección & 1 & 1 & 0 & 0 & 0 & 1 & 0 & A \\
		\textbf{Byte 2} & Status    & POR & FL & 0 & 0 & 0 & 0 & 0 & A \\
		\bottomrule
	\end{tabular}
\end{table}

\begin{table}[H]
	\centering
	\caption{Bytes de configuración de escritura SP5769.}
	\label{tab:sp5769_escritura}
	\renewcommand{\arraystretch}{1.3}
	\begin{tabular}{llccccccccc}
		\toprule
		& & \multicolumn{8}{c}{\textbf{MSB $\longleftarrow$ \hspace{3cm} $\longrightarrow$ LSB}} & \\
		\midrule
		\textbf{Byte 1} & Dirección      & 1 & 1 & 0 & 0 & 0 & 1 & 0 & A \\
		\textbf{Byte 2} & Divisor prog.\ 0 & $2^{14}$ & $2^{13}$ & $2^{12}$ & $2^{11}$ & $2^{10}$ & $2^{9}$ & $2^{8}$ & A \\
		\textbf{Byte 3} & Divisor prog.\ 2 & 2 & 2 & 2 & 2 & 2 & 2 & 2 & A \\
		\textbf{Byte 4} & Control        & 1 & 0 & 0 & 0 & R3 & R2 & R1 & R0 & A \\
		\textbf{Byte 5} & Control        & 0 & 0 & 0 & 0 & 0 & 0 & 0 & 0 & A \\
		\bottomrule
	\end{tabular}
\end{table}

\begin{table}[H]
	\centering
	\caption{Configuración del divisor de referencia (bits R3--R0).}
	\label{tab:divisor_referencia}
	\renewcommand{\arraystretch}{1.25}
	\begin{tabular}{cccc>{\bfseries}c}
		\toprule
		\textbf{R3} & \textbf{R2} & \textbf{R1} & \textbf{R0} & Divisor de referencia \\
		\midrule
		0 & 0 & 0 & 0 & 2   \\
		0 & 0 & 0 & 1 & 4   \\
		0 & 0 & 1 & 0 & 8   \\
		0 & 0 & 1 & 1 & 16  \\
		0 & 1 & 0 & 0 & 32  \\
		0 & 1 & 0 & 1 & 64  \\
		0 & 1 & 1 & 0 & 128 \\
		0 & 1 & 1 & 1 & 256 \\
		1 & 0 & 0 & 0 & 24  \\
		1 & 0 & 0 & 1 & 5   \\
		1 & 0 & 1 & 0 & 10  \\
		1 & 0 & 1 & 1 & 20  \\
		1 & 1 & 0 & 0 & 40  \\
		1 & 1 & 0 & 1 & 80  \\
		1 & 1 & 1 & 0 & 160 \\
		1 & 1 & 1 & 1 & 320 \\
		\bottomrule
	\end{tabular}
\end{table}
	% -------------------------------------------------------

	% -------------------------------------------------------
 -------------------------------------------------------
	\section{Mediciones adicionales}
	\label{anx:mediciones}
	
\begin{figure}[H]
	\centering
	\fcolorbox{azulUNT}{white}{
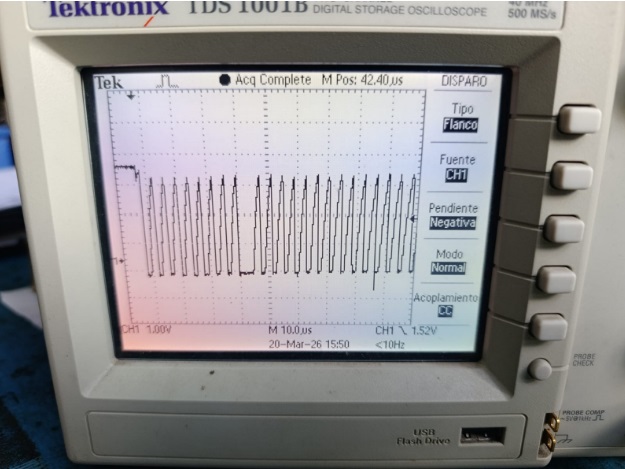
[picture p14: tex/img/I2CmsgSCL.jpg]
		
	}
	\caption{Mensaje I2C, pin SCL}
	\label{fig:i2cmsgscl}
\end{figure}

\begin{figure}[H]
	\centering
	\fcolorbox{azulUNT}{white}{
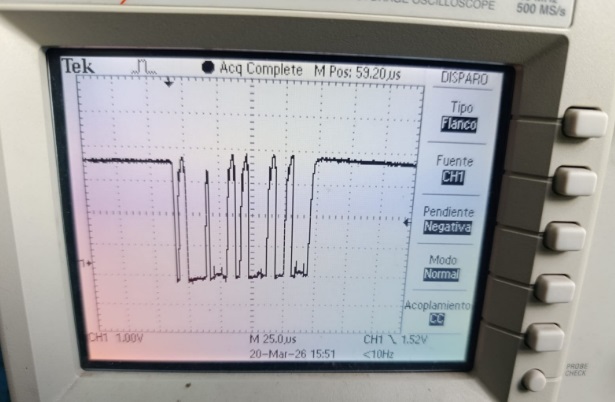
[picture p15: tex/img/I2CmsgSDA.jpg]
		
	}
	\caption{Mensaje I2C, pin SDS}
	\label{fig:i2cmsgsda}
\end{figure}	

\begin{figure}[H]
	\centering
	\fcolorbox{azulUNT}{white}{
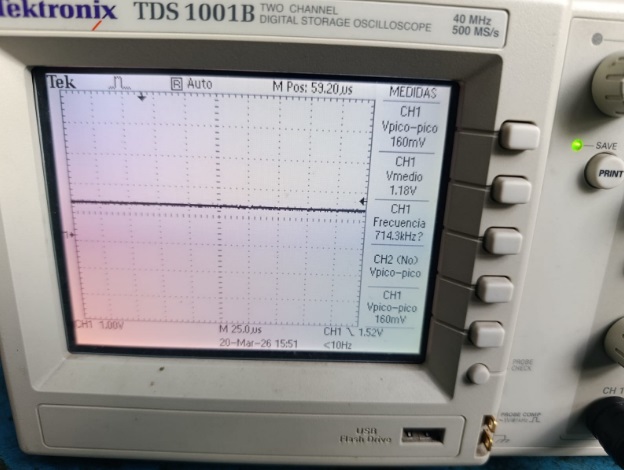
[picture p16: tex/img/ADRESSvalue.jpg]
		
	}
	\caption{Medicion del pin ADRESS, el cual determina la dirección del dispositivo}
	\label{fig:addrs}
\end{figure}	

\begin{figure}[H]
	\centering
	\fcolorbox{azulUNT}{white}{
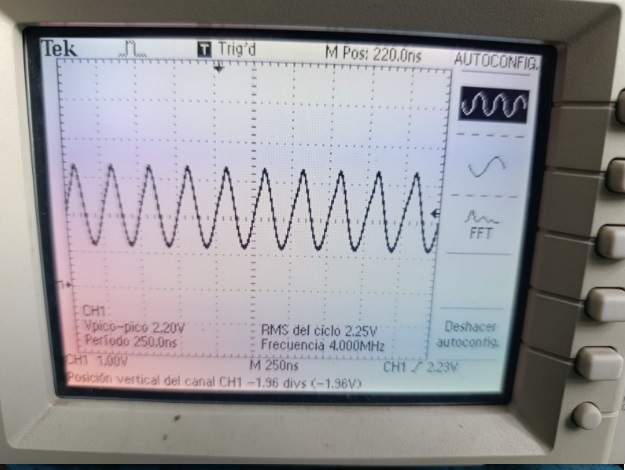
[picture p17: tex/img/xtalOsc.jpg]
		
	}
	\caption{Señal de 4 Mhz en el cristal}
	\label{fig:4mhzosc}
\end{figure}	

\newpage
\section*{Referencias}
\addcontentsline{toc}{section}{Referencias}

\begin{enumerate}[leftmargin=*, label={[\arabic*]}]
	\item Phillips Semiconductors, \textit{SP5769 PLL Frequency Synthesizer Datasheet}. 
	\item Analog Devices (Hittite), \textit{HMC534LP5 VCO Datasheet}. 
	\item Espressif Systems, \textit{ESP32 Technical Reference Manual}. Disponible en: \url{https://www.espressif.com/}
\end{enumerate}
\end{document}

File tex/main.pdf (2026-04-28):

## Universidad Nacional de Tucumán

### Facultad de Ciencias Exactas y Tecnología

### Carrera: Ingeniería en Electrónica

## Reparación y Rediseño de un Sintetizador de Frecuencias en Banda Ku

Informe de Práctica Profesional Supervisada

Autor:
Alexis Vale Jesús Avila

Directores:
Fernando Miranda Bonomi
Juan Ise

Lugar de realización:
Laboratorio de Telecomunicaciones – FaCET – UNT

Período: 2025–2026

Tucumán, Argentina

Resumen

El presente informe describe el proceso de recuperación y rediseño integral de un sintetizador de frecuencias para microondas diseñado para operar en la banda Ku (10,6 GHz a 11,8 GHz), originalmente desarrollado en 2009 y recibido en estado no funcional. El trabajo abarcó el diagnóstico del hardware heredado, la identificación de fallas críticas en el oscilador controlado por tensión (VCO), el reemplazo de componentes dañados y, finalmente, el rediseño completo del circuito impreso (PCB) ante la degradación acumulada por múltiples intervenciones previas.

Como parte del rediseño, el controlador original (microcontrolador PIC) fue reemplazado por una plataforma ESP32, incorporando comunicación Bluetooth e interfaz de usuario. La validación funcional se realizó en el banco de microondas del Laboratorio de Telecomunicaciones, confirmando el enclavamiento del lazo PLL con un error relativo menor al 0,15 % a lo largo de toda la banda operativa.

Palabras clave: sintetizador de frecuencias, banda Ku, PLL, VCO, ESP32, microondas, rediseño PCB.

PPS – Sintetizador de Frecuencias Banda Ku | UNT – FCEyT

Índice

Resumen | 1
1. Introducción | 4
2. Descripción del sistema original | 5
3. Diagnóstico y falla | 7
4. Rediseño del sistema | 10
5. Implementación | 12
6. Validación funcional | 13

7. Resultados y conclusiones | 15
A. Informe de actividades de laboratorio (29/08/2024) | 17
B. Configuración de registros del SP 5769 | 18
C. Mediciones adicionales | 19
Referencias | 21

### 1. Introducción

### 1.1 Contexto del sistema

El equipo objeto del presente trabajo es un sintetizador de frecuencias para microondas diseñado para operar en la banda Ku. Fue desarrollado originalmente en el año 2009 y basa su funcionamiento en un lazo de seguimiento de fase (Phase-Locked Loop, PLL), compuesto por un oscilador controlado por tensión (VCO HMC534LP5) y un sintetizador de frecuencias integrado (SP 5769), controlado mediante bus I2C.

El equipo fue recibido en estado completamente no funcional: presentaba ausencia total de la etapa de alimentación y daños severos en el módulo de control e interfaz (la placa donde residía el microcontrolador encargado de la selección de frecuencia). Adicionalmente, la inspección de la placa principal de RF reveló indicios de intentos de reparación previos no documentados: pistas de cobre recubiertas con estaño, cortes en el ruteo original y puentes improvisados para restituir continuidad eléctrica. Este nivel de deterioro comprometía severamente la integridad de las señales de alta frecuencia.

### 1.2 Aplicación

El propósito del proyecto es el reacondicionamiento integral del equipo para incorporarlo como instrumento de trabajo en el Laboratorio de Telecomunicaciones de la Facultad de Ciencias Exactas y Tecnología de la Universidad Nacional de Tucumán. El sistema restaurado tendrá un fin estrictamente educativo y didáctico, permitiendo a los estudiantes de futuras cursadas y proyectos de investigación realizar prácticas reales con señales de microondas, facilitando la comprensión práctica de conceptos avanzados de RF y lazos de seguimiento de fase (PLL).

### 1.3 Objetivo del trabajo

El objetivo principal es recuperar la operatividad total del sintetizador de microondas. Debido a las fallas acumuladas por deterioro del hardware, la obsolescencia técnica de su implementación física y los intentos de reparación previos infructuosos, el trabajo no se limita a una reparación puntual: requiere un rediseño integral de la PCB para garantizar la estabilidad del sistema, minimizar pérdidas y asegurar su funcionamiento a largo plazo.

### 1.4 Alcance

Para cumplir con los objetivos planteados, el proyecto abarca las siguientes etapas:

### 1. Diagnóstico: Relevamiento detallado del estado actual de los componentes hereda-

dos y análisis crítico del circuito original.

### 2. Reparación inicial: Pruebas de supervivencia de los componentes críticos (VCO y

sintetizador) y montaje de una alimentación provisoria.

### 3. Rediseño de PCB: Migración del diseño esquemático y desarrollo de una nueva

placa de circuito impreso (mediante KiCad y AWR), solucionando los problemas de ruteo e integridad de señal de la versión anterior.

### 4. Validación funcional: Mediciones en banco de microondas para asegurar el encla-

vamiento en frecuencia y la potencia de salida esperada.

### 2. Descripción del sistema original

### 2.1 Arquitectura general

El sintetizador opera bajo el principio de síntesis directa mediante lazo de seguimiento de fase (PLL). Los componentes principales del sistema heredado son:

Sintetizador/PLL: SP 5769 (Phillips/NXP), controlado por bus I2C.

Oscilador controlado por tensión (VCO): HMC534LP5 (Analog Devices/Hittite), encapsulado QFN de 5×5 mm.

Controlador original: Microcontrolador PIC16F873A, encargado de la programación de registros del PLL.

Transistor externo: BCW 31 en configuración amplificador inversor, para adaptar la tensión de sintonía (Vtune) requerida por el VCO (0–13 V) desde la salida de 5 V del sintetizador.

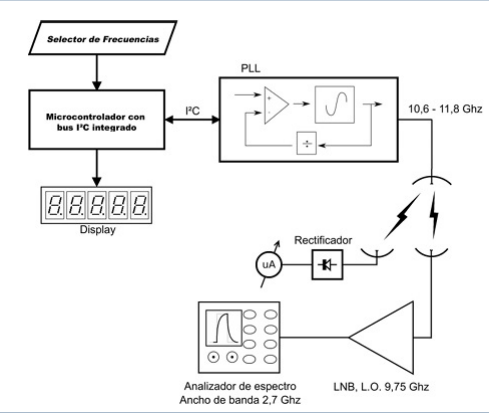
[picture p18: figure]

Figura 1: Diagrama en bloques del sistema original.

### 2.2 Funcionamiento

### 2.2.1 Generación de frecuencia

El VCO genera una señal de RF cuya frecuencia depende de la tensión aplicada en su pin de sintonía (Vtune). El sintetizador SP 5769 implementa el lazo PLL: divide la señal de salida del VCO mediante divisores programables, la compara con una referencia interna de cristal y genera una señal de error (bomba de carga) que, a través del amplificador externo con el BCW 31, ajusta Vtune hasta que la frecuencia de salida coincide con la programada.

### 2.2.2 Control e interfaz

El PIC16F873A (en el diseño original) programa los registros internos del SP 5769 vía bus I2C, estableciendo los valores de los divisores de frecuencia que determinan la frecuencia de síntesis.

### 2.2.3 Rango de salida RF

El sistema está diseñado para operar en el rango de 10,6 GHz a 11,8 GHz, cubriendo la banda Ku de interés.

### 2.3 Limitaciones detectadas

Dependencia del SP 5769: Al tratarse de un componente específico ya presente en la placa original, su disponibilidad en el mercado actual es limitada. Durante el proyecto, el SP 5769 original resultó dañado, requiriéndose la adquisición de uno nuevo con distinto encapsulado, lo que obligó a adaptar la huella en la PCB rediseñada.

Dificultad de mantenimiento: Las múltiples reparaciones sucesivas sobre la placa original fueron degradando progresivamente las soldaduras y la integridad física de los componentes, haciendo inevitables el rediseño completo de la PCB y el reemplazo con componentes nuevos.

Encapsulado QFN del VCO: El HMC534LP5 carece de pines expuestos tradicionales, concentrando su disipación térmica en la almohadilla central inferior. Esto hace que su soldadura y reemplazo sean técnicamente exigentes y requieran equipamiento especializado.

El microcontrolador usado es muy antiguo Se decidipo cambiar por un ESP32 por su menor precio, ensamblado comodo en pcb, posibilidad de programar en C/Arduino y su conexión Bluetooth.

### 3. Diagnóstico y falla

### 3.1 Análisis inicial e implementación de hardware de prueba

El proceso de diagnóstico comenzó con el estudio de las hojas de datos (datasheets) de los componentes críticos: el sintetizador SP 5769 y el VCO HMC534LP5. Se determinaron los niveles de tensión necesarios para la operación y se realizó una inspección visual del conexionado.

Dado que el sistema se recibió sin su etapa de alimentación original, fue necesario utilizar hardware auxiliar:

Alimentación de 12 V: Se diseñó y fabricó una fuente regulable de 12 V utilizando el método de transferencia térmica (planchado) para la creación de la placa de circuito impreso (PCB).

Alimentación de 5 V: Para la lógica de control, se utilizó directamente la salida regulada de 5 V provista por la placa de desarrollo ESP32.

Interfaz de conexión (Shield ESP32): Se fabricó una placa adaptadora (tipo poncho o shield), también mediante el método de transferencia térmica, para interconectar de manera segura la ESP32 con la placa de RF heredada.

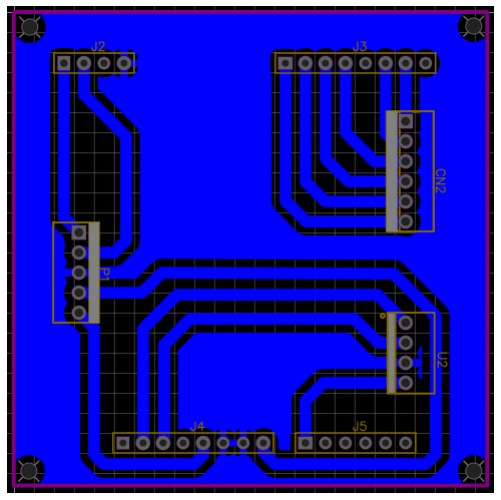
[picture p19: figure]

(a) Vista superior | (b) Vista inferior

Figura 2: Shield ESP32 implementado provisionalmente.

### 3.2 Desarrollo de firmware

El código fuente original (desarrollado para PIC16F873A) resultó de difícil comprensión y adaptación. Se decidió descartar el firmware existente y desarrollar uno nuevo desde cero sobre la plataforma ESP32, basándose estrictamente en los registros y diagramas de tiempos especificados en la hoja de datos del SP 5769. El repositorio del nuevo firmware se encuentra disponible en: https://github.com/gsuckz/pll

Tras múltiples pruebas y ajustes de sincronización, se logró establecer comunicación exitosa a través del bus I2C entre la ESP32 y el SP 5769, confirmando que la lógica digital del sintetizador se encontraba operativa. Se detectó y corrigió además un error en los valores asignados a uno de los divisores programables.

### 3.3 Falla principal: daño en el VCO

### 3.3.1 Síntomas observados

El día 29 de agosto de 2024 se realizaron las primeras pruebas formales sobre el banco de microondas (ver Informe de Actividades de Laboratorio adjunto en Anexo). Los síntomas observados fueron:

Ausencia total de potencia de salida de RF, confirmada con sensor rectificador con medidor analógico y con analizador de RF digital.

El PLL no lograba el enclavamiento (no lock) a pesar de que el SP 5769 respondía correctamente a los comandos I2C y permitía fijar la frecuencia programada.

Al analizar el lazo cerrado, el sintetizador intentaba ajustar Vtune para corregir la frecuencia, pero no recibía señal de realimentación (feedback) por parte del VCO.

### 3.3.2 Diagnóstico conclusivo

Descartados errores en el código (corregidos previamente), en el conexionado y en los niveles de alimentación, se concluyó que el VCO HMC534LP5 estaba dañado irreversiblemente de forma previa a la recepción del equipo.

### 3.4 Reemplazo del VCO (encapsulado QFN)

La confirmación de la falla del VCO obligó a su reemplazo, lo cual representó un desafío técnico significativo debido al encapsulado QFN de 5×5 mm: carece de pines expuestos y concentra su disipación térmica en la almohadilla central inferior. Se aplicaron técnicas de soldadura térmica adecuadas para este tipo de empaquetado, logrando extraer el componente dañado y montar exitosamente la unidad de reemplazo. Para este procedimiento fue necesario recurrir a la asistencia técnica de DIGICOM, dado que el proceso requería equipamiento especializado.

### 3.5 Problemas de alimentación y reestructuración

Tras la instalación del nuevo VCO, el sistema mostraba actividad pero no lograba enclavarse. Se detectó que el regulador interno de la ESP32 no poseía la capacidad de corriente suficiente para alimentar simultáneamente la lógica digital, el sintetizador y el VCO. La caída en la línea de 5 V (por debajo de 4,5 V) desestabilizaba por completo el lazo de sintonía.

Se reestructuró la arquitectura de alimentación:

Separación de fuentes: Se incorporó una fuente conmutada (switching) dedicada exclusivamente a proveer los 5 V robustos que demandan los componentes de RF (VCO y sintetizador), con masa común a la etapa de control digital (ESP32).

Gestión de Vtune: Se verificó el correcto funcionamiento del amplificador inversor discreto (BCW 31), alimentado por la línea de 12 V y comandado por la salida Drive del SP 5769, encargado de proveer la amplitud de tensión necesaria (0–13 V) para el control del VCO.

Adicionalmente, se identificó el ventilador (cooler) acoplado al disipador térmico del VCO como posible fuente de ruido. De manera preventiva, se diseñó e implementó un filtro activo pasa-bajos compuesto por un transistor NPN 2N2222 en configuración emisor seguidor, una resistencia de base de 33 kΩ y un capacitor de 10 µF, logrando desacoplar la línea de alimentación de RF de las posibles interferencias.

### 3.6 Falla y obsolescencia definitiva del hardware heredado

Tras múltiples intervenciones sobre la PCB original, la placa acumuló un deterioro físico significativo. El reemplazo del VCO original, que se encontraba dañado, implicó varias operaciones de desoldado y resoldado que degradaron las pistas y almohadillas. Durante estas tareas, un segundo VCO también resultó dañado debido a un error de manipulación, lo que agravó el estado general del circuito impreso.

Como consecuencia de estas intervenciones sucesivas, la integridad mecánica y eléctrica de la PCB se vio comprometida, volviendo poco confiable su reutilización. En este contexto, se tomó la decisión de diseñar una nueva placa, no solo para recuperar la funcionalidad sino también para introducir mejoras constructivas, como el reemplazo del puerto RS232 por conectores tipo peine que facilitan la interconexión y el mantenimiento.

Durante la etapa de puesta en marcha del nuevo hardware, se detectó la ausencia de respuesta del PLL SP5769 a través de la interfaz I2C. Tras las verificaciones correspondientes, se concluyó que el dispositivo se encontraba dañado. Dado que no fue posible conseguir el mismo componente en el encapsulado original, se optó por adquirir una variante disponible en el mercado con distinto encapsulado (se adquirió por error un chip en formato SSOP 16 en lugar del original SOP), lo que requirió una nueva iteración del diseño de la PCB para adaptar la huella al formato SSOP 16.

De este modo, el proceso de rediseño no solo respondió al deterioro físico de la placa original, sino también a la necesidad de adaptación frente a la disponibilidad de componentes, consolidando una solución funcional sobre una nueva plataforma de hardware.

### 4. Rediseño del sistema

### 4.1 Motivaciones

Las principales razones que llevaron al rediseño completo fueron:

1. Daño físico acumulado en la PCB original por múltiples reparaciones sucesivas.

### 2. Pérdida del SP 5769 original y necesidad de adaptación al nuevo encapsulado dispo-

nible en el mercado.

### 3. Garantizar la integridad de señal en alta frecuencia (banda Ku), imposible de asegurar

sobre una placa con pistas dañadas y puentes improvisados.

### 4. Facilitar el mantenimiento y la reproducibilidad del equipo para uso educativo a

largo plazo.

### 4.2 Cambios principales respecto al diseño original

Tabla 1: Comparación entre el sistema original y el rediseñado.

Aspecto | Sistema original | Sistema rediseñado
Controlador | PIC16F873A | ESP32
Interfaz de usuario | Sin interfaz Bluetooth | Bluetooth (app móvil / ter- minal)
PCB | Placa heredada (2009), da- ñada | PCB rediseñada en KiCad
Encapsulado PLL | SP 5769 (encapsulado origi- nal) | SP 5769 (nuevo encapsulado, huella adaptada)
Arquitectura RF | PLL + VCO externo | PLL + VCO externo (sin cambios)
Firmware | Código PIC (código fuente inaccesible) | Firmware nuevo en ESP32 (repositorio abierto)
Alimentación | Fuente interna (original per- dida) | Fuente switching dedicada para RF + 5 V lógica

### 4.3 Cambio de plataforma de control

### 4.3.1 Sistema original: PIC16F873A

El microcontrolador PIC16F873A ejercía un control básico del PLL: programaba los divisores de frecuencia del SP 5769 mediante I2C a partir de una selección fija de frecuencias.

### 4.3.2 Sistema rediseñado: ESP32

La plataforma ESP32 ofrece significativas mejoras:

Configuración del PLL vía I2C: Manteniendo compatibilidad total con el SP 5769.

Interfaz Bluetooth: Permite configurar la frecuencia de síntesis de forma inalámbrica desde una aplicación de terminal Bluetooth en dispositivo móvil o PC.

Visualización en pantalla: Una pantalla lcs 16x2 con teclado

Mayor flexibilidad: El firmware puede actualizarse fácilmente; el repositorio es abierto y documentado.

### 4.3.3 Justificación de la decisión

La migración a ESP32 se justifica por la mejora sustancial en usabilidad (interfaz Bluetooth elimina la necesidad de conexión física para operar el equipo), la mayor flexibilidad de control y programación, y la disponibilidad inmediata del hardware en el contexto del laboratorio.

### 4.4 Decisiones de diseño relevantes

Resumen de decisiones de diseño

Mantener: Arquitectura PLL + VCO externo, sintetizador SP 5769, VCO HMC534LP5.
Cambiar: Plataforma de control (PIC → ESP32), PCB completa (rediseño en KiCad), encapsulado del SP 5769 (adaptación de huella).
Incorporar: Fuente switching dedicada para RF, filtro activo en Vtune, firmware abierto y documentado, interfaz Bluetooth.

### 5. Implementación

### 5.1 Diseño de PCB

### 5.1.1 Consideraciones de alta frecuencia

El diseño de la nueva PCB debió contemplar las exigencias propias de los circuitos operando en la banda Ku:

Integridad de señal RF: Las líneas de transmisión de RF se diseñaron como striplines con impedancia característica controlada de 50 Ω.

Cálculo de dimensiones: Se utilizó el software AWR Microwave Office para determinar los anchos de pista y separaciones necesarios para lograr la adaptación de impedancias en las frecuencias de trabajo (banda Ku).

Software EDA: El ruteo y el diseño del layout se realizaron en KiCad.

Adaptación de huella: El nuevo encapsulado del SP 5769 adquirido difería del original, por lo que se generó una nueva huella (footprint) adaptada en KiCad.


Figura 3: Layout de la PCB rediseñada. Usando la huella SSOP 16

### 5.2 Montaje e integración

Soldadura de componentes SMD, incluyendo el VCO HMC534LP5 (QFN 5×5 mm) y el nuevo SP 5769 con encapsulado adaptado.

Programación inicial del ESP32 con el nuevo firmware.

Integración mecánica: se diseñó y fabricó mediante impresión 3D un gabinete a medida para alojar el sistema completo y proteger las conexiones.

### 6. Validación funcional

### 6.1 Metodología de medición

Las mediciones de validación se realizaron en el banco de microondas del Laboratorio de Telecomunicaciones de la FCEyT–UNT. Para determinar la frecuencia real emitida (f0), se midió la longitud de onda dentro de la guía de onda (λg) utilizando el ondámetro de ranura resonante. Conociendo la dimensión transversal de la guía utilizada (2a = 45,72 mm, que define la longitud de onda de corte λc), se calculó la longitud de onda en el espacio libre (λ0) mediante la relación:

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
Finalmente, la frecuencia de oscilación se obtuvo como f0 = c/λ0, donde c es la velocidad de la luz en el vacío.

### 6.2 Ensayos realizados

### 6.2.1 Prueba de límites físicos del VCO (bomba de carga)

Para verificar la excursión máxima del VCO instalado, se forzaron por software los estados extremos de la bomba de carga del SP 5769:

CP-Disable (límite inferior): Con la bomba de carga deshabilitada, la tensión de sintonía cae al mínimo. Se midió λg = 42,52 mm, obteniendo una frecuencia límite inferior de fmin ≈ 9,3 GHz.

CP-Sink (límite superior): Con la bomba de carga forzada a drenar corriente máxima, la tensión alcanza el límite superior. Se midió λg = 29,12 mm, obteniendo una frecuencia límite superior de fmax ≈ 12,21 GHz.

Estos resultados confirman que el hardware supera holgadamente el rango requerido (10,6–11,8 GHz).

### 6.2.2 Validación del enclavamiento de frecuencia

Se realizó un barrido discreto programando el sintetizador en saltos de 300 MHz a lo largo de la banda de trabajo. La Tabla 2 muestra los resultados comparativos entre la frecuencia programada (fprog) y la frecuencia medida (fmed).

Tabla 2: Resultados de validación del enclavamiento PLL.

fprog (GHz) λg medida (mm) fmed (GHz) Error relativo ( %)

10,600 | 35,94 | 10,608 | 0,075
10,900 | 34,41 | 10,911 | 0,101
11,200 | 33,00 | 11,210 | 0,089
11,500 | 31,69 | 11,518 | 0,157
11,800 | 30,52 | 11,818 | 0,153

### 6.2.3 Barrido de frecuencia (frequency sweep)

Se implementó y ensayó por software la función de barrido de frecuencia, verificando que el sistema puede recorrer toda la banda operativa de forma continua y estable.

### 6.3 Resultados

Síntesis de resultados

El PLL logró enclavamiento (lock) en todos los puntos de frecuencia ensayados. El error relativo máximo observado fue del 0,157 %, considerado despreciable para la aplicación educativa prevista.
El VCO cubre con holgura el rango Ku requerido: desde 9,3 GHz hasta 12,21 GHz.
El sistema operó de forma estable a lo largo de toda la banda 10,6–11,8 GHz.

### 6.4 Hardware principal y transmisión de la señal

El sistema se centra en la generación, transmisión y recepción de ondas electromagnéticas en el rango de las microondas (banda Ku). El núcleo de emisión es el sintetizador operando en un rango de 10,6 GHz a 11,8 GHz. Para acondicionar y caracterizar la señal, el banco cuenta con atenuadores de baja precisión (hasta 20 dB) y de alta precisión (ajuste micrométrico de 0,01 mm), además de un ondámetro de cavidad resonante.

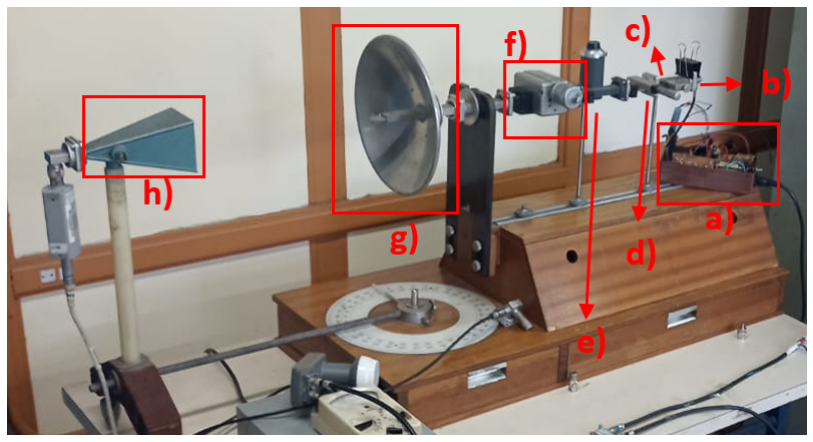
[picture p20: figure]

Figura 4: Configuración del banco de microondas.

La onda viaja por la guía hasta la antena transmisora, la cual está conformada por un dipolo y un reflector parabólico que irradia con una polarización lineal vertical. En el extremo receptor, el campo es captado por una antena tipo bocina piramidal (Horn). Para cuantificar la energía recibida, la antena se acopla a un diodo rápido Schottky montado en posición vertical, el cual rectifica la señal de RF para ser leída por un amperímetro analógico.


(a) Transmisor parabólico | (b) Receptor de bocina

Figura 5: Antenas de transmisión y recepción en el banco.

### 6.5 Mediciones adicionales en banco con LNB

Como actividad extra, se integró en la recepción un LNB (Low Noise Block) dual para bajar en frecuencia la señal de la banda Ku y permitir su análisis con un analizador de espectro de menor rango. Este dispositivo capta las frecuencias y las amplifica con bajo ruido, realizando una conversión a frecuencia intermedia (IF) mediante un oscilador local (OL).

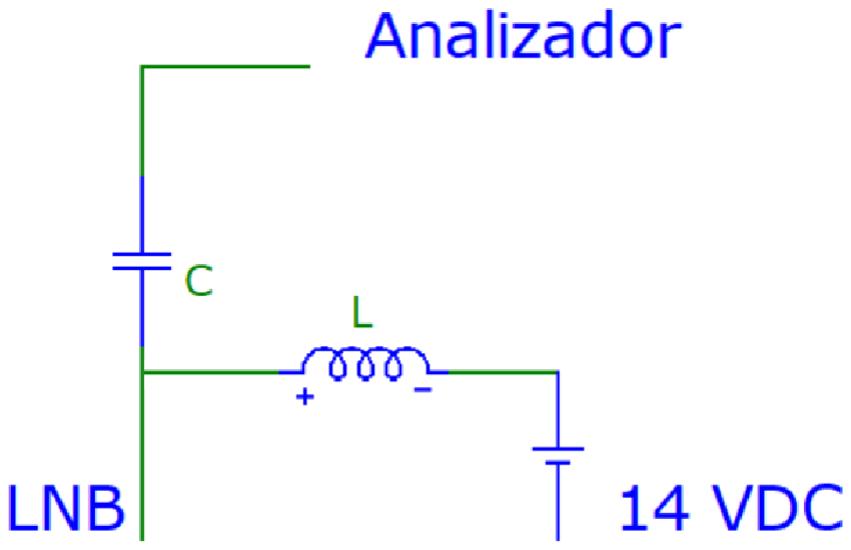
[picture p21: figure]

(a) Conexión del LNB al montaje | (b) LNB dual

Figura 6: Integración de LNB en el banco experimental.

Inyector y filtro activo LC (Winegard PS-1403): Para la correcta operación del LNB, se empleó un filtro inyector de continua (Winegard PS-1403) actuando como bias tee. Esto permitió alimentar el LNB con continua sin afectar el paso de la señal de RF hacia el analizador de espectro, protegiendo sus puertos de entrada.


Figura 7: Filtro activo LC empleado para aislamiento y alimentación.

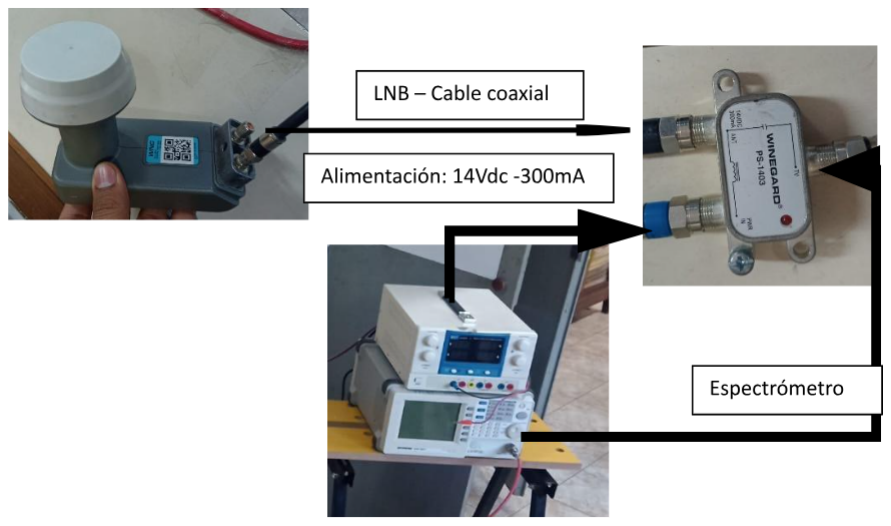
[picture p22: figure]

Figura 8: Esquema de conexiones con el analizador de espectro.

Lecturas de frecuencia convertida: En el analizador de espectro se identificó correctamente el tono convertido a frecuencia intermedia fIF ≈ 1,9 GHz.


Figura 9: Tono medido en el analizador de espectro.

Sabiendo la frecuencia transmitida por el oscilador (fRF ) y la frecuencia detectada en el analizador (fIF ), se verifica empíricamente la frecuencia del oscilador local (fOL) interno del LNB utilizando la relación fundamental de los mezcladores:

fOL = fRF − fIF = 11,65 GHz − 1,90 GHz = 9,75 GHz | (2)

### 7. Resultados y conclusiones

### 7.1 Logros obtenidos

Se logró recuperar la funcionalidad completa del sintetizador de frecuencias en banda Ku. El sistema final opera correctamente en el rango 10,6–11,8 GHz con un error de frecuencia inferior al 0,16 %, confirmado mediante mediciones en banco de microondas.

El rediseño integral de la PCB permitió:

Adaptar el diseño a los encapsulados de componentes actualmente disponibles en el mercado.

Resolver los problemas de integridad de señal presentes en la placa heredada.

Garantizar la reproducibilidad y el mantenimiento del equipo para uso educativo a largo plazo.

Mejorar sustancialmente la interfaz de usuario mediante la incorporación de comunicación Bluetooth y una pantalla de visualización.

### 7.2 Lecciones aprendidas

La importancia del diseño de PCB orientado a la integridad de señal en alta frecuencia desde la etapa de concepción, para evitar problemas de reparabilidad en el futuro.

La necesidad de documentar todos los intentos de reparación sobre hardware heredado para facilitar el diagnóstico posterior.

El valor de contar con equipamiento especializado (estación de soldadura para QFN, banco de microondas) para proyectos de RF en banda Ku.

A. Informe de actividades de laboratorio (29/08/2024)

Fecha: 29 de agosto de 2024
Responsable: Jesús Avila
Proyecto: Reparación de Sintetizador de Frecuencias Ubicación: Laboratorio de Telecomunicaciones

Descripción del trabajo realizado. Se realizaron tareas de diagnóstico y reparación en un sintetizador compuesto por un módulo de RF con sintetizador SP 5769, VCO y placa ESP32 (interfaz Bluetooth). El firmware de la ESP32 había sido validado previamente (lógica mediante TDD y comunicación I2C con una BluePill programada con la dirección del SP 5769).

Procedimiento.

1. Conexión inicial: Se conectó la ESP32 al módulo de RF a través del conector DB9.

### 2. Verificación de conexiones: Con multímetro se detectó y corrigió un error en la

referencia de conexiones.

### 3. Prueba de comunicación: Usando la aplicación Bluetooth Terminal, se confirmó

que el SP 5769 respondía correctamente, aunque no lograba el enclavamiento.

### 4. Verificación de potencia de salida: Tanto con sensor rectificador/medidor analó-

gico como con analizador de RF digital, se constató ausencia total de potencia de salida.

Resultados y conclusiones. La ausencia de potencia de salida y la falta de enclavamiento indicaron falla en el VCO o en el transistor externo. Se propuso un análisis más profundo de ambos componentes para confirmar la causa.

—————————–

B. Configuración de registros del SP 5769

Tabla 3: Bytes en modo lectura del SP5769.

MSB ←− | −→ LSB
Byte 1 Dirección | 1 | 1 | 0 0 0 1 0 | A
Byte 2 Status | POR FL 0 0 0 0 0 | A

Tabla 4: Bytes de configuración de escritura SP5769.

MSB ←− | −→ LSB
Byte 1 Dirección | 1 | 1 | 0 | 0 | 0 | 1 | 0 | A
Byte 2 Divisor prog. 0 2
| 14 | 2
| | 13 | 2
| | | 12 | 2
| | | | 11 | 2
| | | | | 10 | 2
| | | | | | 9 | 2
| | | | | | | 8 | A
Byte 3 Divisor prog. 2 | 2 | 2 | 2 | 2 | 2 | 2 | 2 | A
Byte 4 Control | 1 | 0 | 0 | 0 | R3 R2 R1 R0 A
Byte 5 Control | 0 | 0 | 0 | 0 | 0 | 0 | 0 | 0 | A

Tabla 5: Configuración del divisor de referencia (bits R3–R0).

R3 R2 R1 R0 Divisor de referencia

0 | 0 | 0 | 0 | 2
0 | 0 | 0 | 1 | 4
0 | 0 | 1 | 0 | 8
0 | 0 | 1 | 1 | 16
0 | 1 | 0 | 0 | 32
0 | 1 | 0 | 1 | 64
0 | 1 | 1 | 0 | 128
0 | 1 | 1 | 1 | 256
1 | 0 | 0 | 0 | 24
1 | 0 | 0 | 1 | 5
1 | 0 | 1 | 0 | 10
1 | 0 | 1 | 1 | 20
1 | 1 | 0 | 0 | 40
1 | 1 | 0 | 1 | 80
1 | 1 | 1 | 0 | 160
1 | 1 | 1 | 1 | 320

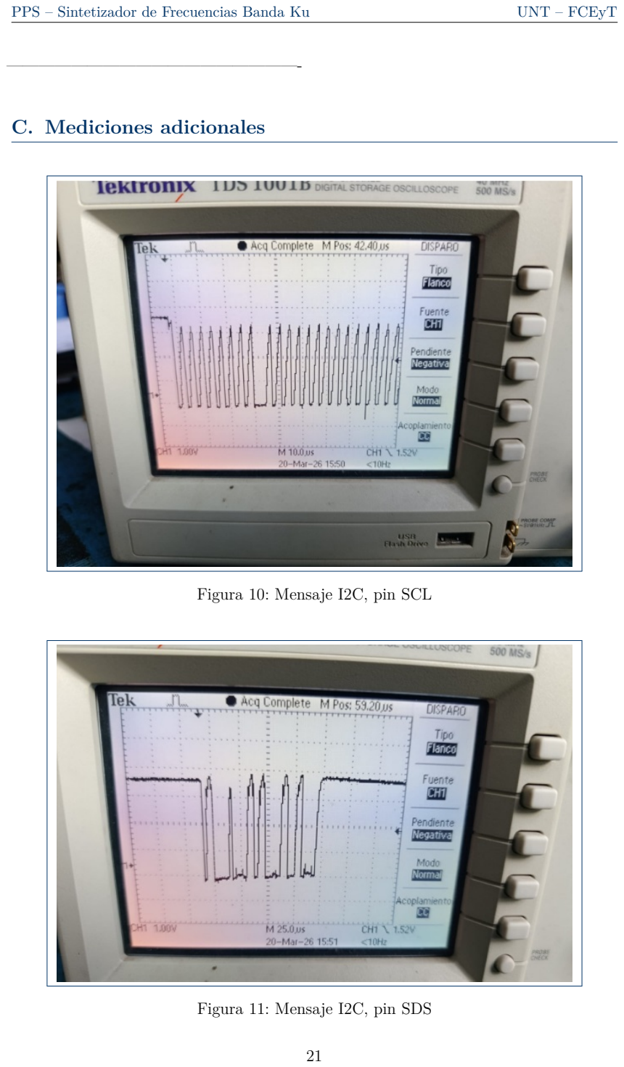
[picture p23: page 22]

——————————————————-

C. Mediciones adicionales

Figura 10: Mensaje I2C, pin SCL

Figura 11: Mensaje I2C, pin SDS

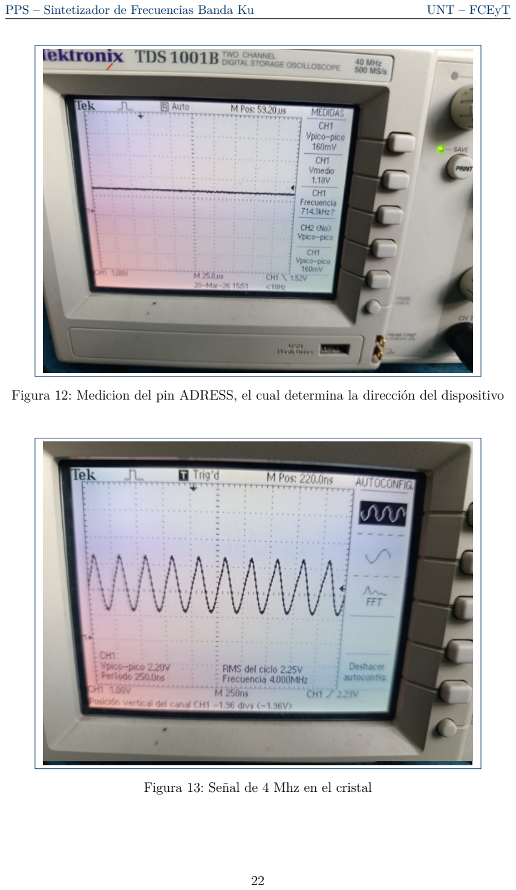
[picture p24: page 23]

Figura 12: Medicion del pin ADRESS, el cual determina la dirección del dispositivo

Figura 13: Señal de 4 Mhz en el cristal

Referencias

[1] Phillips Semiconductors, SP5769 PLL Frequency Synthesizer Datasheet.
[2] Analog Devices (Hittite), HMC534LP5 VCO Datasheet.
[3] Espressif Systems, ESP32 Technical Reference Manual. Disponible en: https://www.espressif.com/

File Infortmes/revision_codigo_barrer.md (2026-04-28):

# Revisión de Código: Función de Barrido (`barrer`)

Tras analizar en profundidad el código del parser de comandos (`comandos.c`) y la lógica del sintetizador (`sintetizador.cpp`), he detectado **errores críticos en la función de barrido** que impedirán su correcto funcionamiento en la mayoría de los casos prácticos.

A continuación, se detalla por qué la función `barrer` fallará y las razones matemáticas de los bugs.

## 1. Conflicto de Límites (Siempre arrojará error de Buffer)

Existe una contradicción entre las validaciones del comando y la capacidad del buffer, lo que hace que el barrido casi siempre aborte.

**En `comandos.c`:**
Se obliga a que la diferencia entre la frecuencia máxima y mínima sea de al menos 100 MHz:
```c
if (cmd->parametro[1] >= (cmd->parametro[2] + 100)) { // Falla si max - min < 100
```

**En `sintetizador.cpp` (`configurarBarrido`):**
Se calcula la cantidad de pasos de frecuencia basándose en un paso mínimo de 1 MHz:
```c
numeroPasosf = (frecuenciaBarridoMax - frecuenciaBarridoMin) / FRECUENCIA_PASO_MIN; 
// Como mínimo, esto será 100.
```
Luego, se toma el máximo entre `numeroPasosf` y los pasos por tiempo (`numeroPasosT`), por lo que `numeroPasos` **siempre será mayor o igual a 100**.

El problema ocurre en la siguiente validación:
```c
if (numeroPasos > TAMANO_BUFFER_BARRIDO / 2) { 
    SerialBT.println("ERROR: Numero de pasos excede el tamaño del buffer de barrido");
    return;
}
```
Como `TAMANO_BUFFER_BARRIDO` es 200, el límite máximo permitido de pasos es 100.
**Consecuencia:** Si el usuario intenta hacer un barrido de 10.6 GHz a 11.0 GHz (diferencia de 400 MHz), `numeroPasos` será al menos 400. La validación fallará, arrojará error y el barrido **no se ejecutará**. La única forma en que funcione es si se piden *exactamente* 100 MHz de diferencia y un tiempo menor o igual a 100 ms.

---

## 2. División Entera (El barrido se queda estancado en la misma frecuencia)

Incluso si sorteáramos el problema del buffer (aumentando su tamaño), el barrido fallará en cambiar las frecuencias debido a un error de tipos de datos.

El paso de frecuencia se calcula así (usando enteros):
```c
pasoFrecuencia = ((frecuenciaBarridoMax - frecuenciaBarridoMin) / numeroPasos);
```
Si el usuario pide hacer un barrido de 100 MHz en 500 ms, entonces `numeroPasos` se define por el tiempo y vale 500.
Al calcular: `100 / 500`, **el resultado en división entera en C/C++ es `0`**.

Más abajo, en el bucle que llena el buffer:
```c
temp += pasoFrecuencia; 
```
Como `pasoFrecuencia` es 0, a `temp` se le suma 0 en cada iteración.
**Consecuencia:** El buffer se llenará con la frecuencia inicial repetida 500 veces. El sintetizador hará "pasos" en el tiempo, pero la frecuencia se mantendrá constante, sin barrer realmente.

---

## 3. Inconsistencia de Unidades en `numeroPasosT`

En la función se calcula el número de pasos por tiempo de esta manera:
```c
numeroPasosT = duracion / FRECUENCIA_PASO_MIN; // FRECUENCIA_PASO_MIN = 1
```
Se está dividiendo un tiempo (milisegundos) por una constante que representa Frecuencia (MHz). Esto carece de sentido físico. Lo correcto sería definir un "tiempo de paso mínimo" (`TIEMPO_PASO_MIN_MS`) y usarlo para calcular cuántos pasos temporales caben en la duración total.

---

## Conclusión

Actualmente, la función `barrer` **no es funcional** para la mayoría de los escenarios. 

### Soluciones Propuestas:
1. **Aumentar drásticamente el tamaño del buffer:** Si se desea permitir barridos de hasta 1200 MHz (10.6 a 11.8), `TAMANO_BUFFER_BARRIDO` debería ser al menos de 2400. Sin embargo, esto consumirá mucha memoria RAM en el microcontrolador.
2. **Generación al Vuelo (Sin Buffer):** En lugar de precalcular todas las frecuencias en un buffer gigante, se debería calcular y enviar la frecuencia deseada directamente en cada ciclo de la función `SintetizadorTickBarrido()`.
3. **Usar `float` para el paso de frecuencia:** `pasoFrecuencia` y `temp` deberían ser variables de punto flotante para acumular fracciones de MHz cuando los pasos de tiempo sean mayores que la diferencia de frecuencia, enviando el valor redondeado al sintetizador.

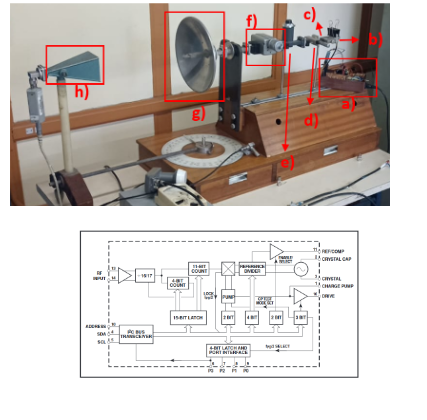
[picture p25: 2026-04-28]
tex/img/Hardware Principal y Sintetizador en Banda Ku.png

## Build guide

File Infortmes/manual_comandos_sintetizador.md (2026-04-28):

# Manual de Usuario - Sintetizador de Banda Ku

Este manual describe el funcionamiento y los comandos disponibles para operar el sintetizador de frecuencias en banda Ku (10.6 GHz a 11.8 GHz) a través de un terminal por puerto serie o Bluetooth.

## Conexión y Configuración

El sintetizador permite la comunicación inalámbrica a través de Bluetooth o mediante conexión serie tradicional.
- **Dispositivo Bluetooth:** "Sintetizador de Banda Ku"
- **Baudrate:** 9600 bps

## Formato de los Comandos

Los comandos no son sensibles a mayúsculas o minúsculas (`FREC` es igual a `frec`).
Cada comando y sus respectivos parámetros (si los tiene) deben ir separados por espacios. El comando se ejecutará al enviar un carácter de terminación (`\n` o al presionar Enter).

---

## Lista de Comandos

### `frec` o `frecuencia`
Fija una nueva frecuencia de salida constante en el sintetizador.
- **Parámetros:** 1 (Frecuencia en MHz).
- **Rango permitido:** 10600 a 11800.
- **Ejemplo:** `frec 11000` (Ajusta la frecuencia a 11.0 GHz).
- **Respuesta:** `Frecuencia fijada en: 11000 MHz`

### `frec?` o `frecuencia?`
Consulta la frecuencia configurada actualmente.
- **Parámetros:** 0.
- **Ejemplo:** `frec?`
- **Respuesta:** `Frecuencia fijada en: <frecuencia> MHz`

### `barrer`
Inicia un barrido de frecuencias continuo entre un límite inferior y uno superior, en un tiempo determinado.
- **Parámetros:** 3
  1. `tiempo_ms`: Duración total del barrido en milisegundos (Mínimo: 100).
  2. `f_min`: Frecuencia inicial en MHz (Rango: 10600 - 11800).
  3. `f_max`: Frecuencia final en MHz (Rango: 10600 - 11800).
- **Restricción:** La diferencia entre la frecuencia máxima y mínima debe ser de al menos 100 MHz.
- **Ejemplo:** `barrer 500 10600 11000` (Realiza un barrido desde 10.6 GHz hasta 11.0 GHz en 500 ms).

### `stop`
Detiene un barrido de frecuencias en curso. La frecuencia quedará fijada en el último valor alcanzado al momento de detenerlo.
- **Parámetros:** 0.
- **Ejemplo:** `stop`

### `estado`
Consulta el estado de enclavamiento (Lock) del lazo de enganche de fase (PLL) y el estado de la alimentación.
- **Parámetros:** 0.
- **Ejemplo:** `estado`
- **Respuestas posibles:**
  - `Estado: Enclavado!`
  - `Estado: No Enclavado`
  - `Estado: Error de Alimentación`

### `id?`
Retorna el identificador y la versión del firmware del equipo.
- **Parámetros:** 0.
- **Ejemplo:** `id?`
- **Respuesta:** `Sintetizador de Frecuencias en Banda Ku v0.1`

### Modos Especiales y de Prueba
Estos comandos alteran el comportamiento interno del sintetizador para tareas de calibración o testeo.

- **`iniciar`**: Reinicializa el sintetizador y lo devuelve a su modo de funcionamiento NORMAL.
- **`cpdis`**: Deshabilita la bomba de carga (Charge Pump Disabled).
- **`cpsnk`**: Fuerza la bomba de carga en modo sumidero (Charge Pump Sink).
- **`cpsrc`**: Fuerza la bomba de carga en modo fuente (Charge Pump Source).
- **`cft`**: Conecta la salida del comparador de fase al pin de Test.

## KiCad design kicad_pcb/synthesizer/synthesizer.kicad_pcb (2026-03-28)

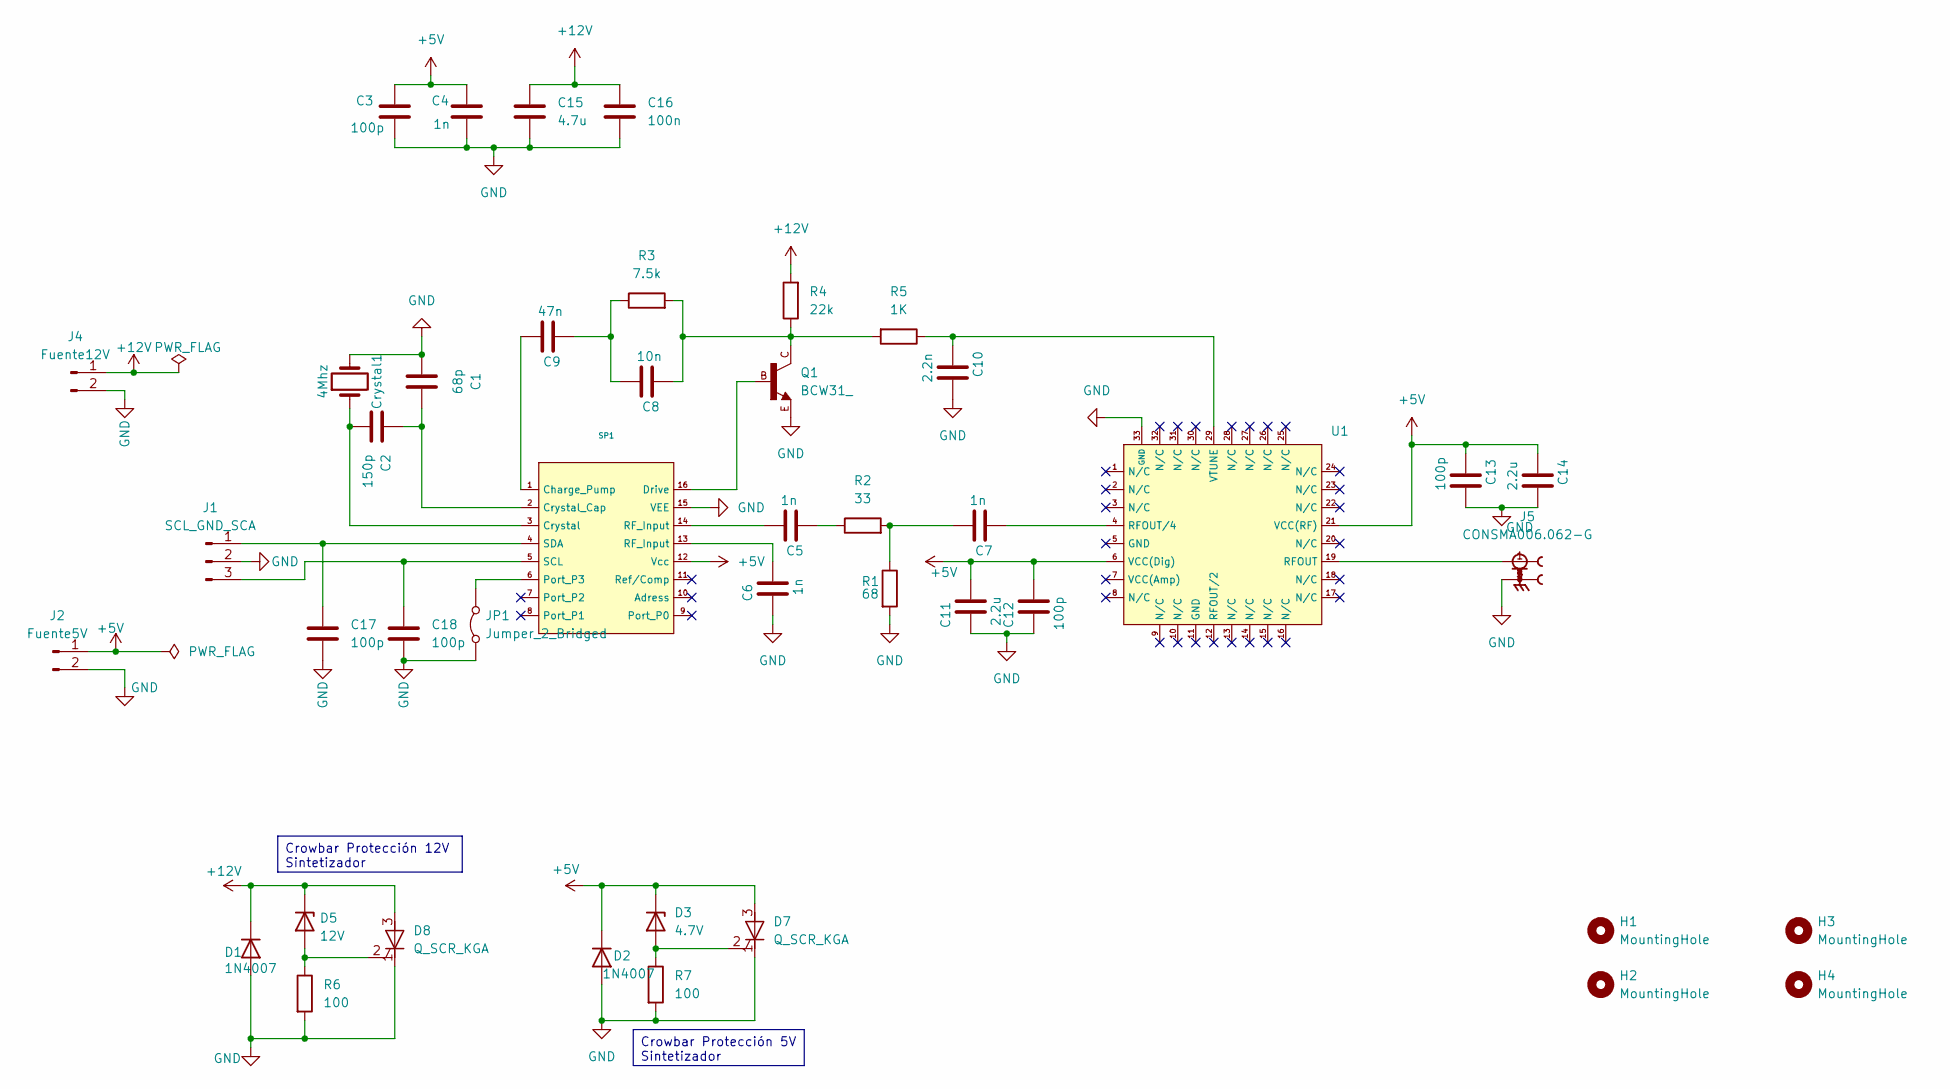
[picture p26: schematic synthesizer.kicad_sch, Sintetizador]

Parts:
C1: 68p; C_0805_2012Metric_Pad1.18x1.45mm_HandSolder
C2: 150p; C_0805_2012Metric_Pad1.18x1.45mm_HandSolder
C3, C12, C13, C17, C18: 100p; C_0805_2012Metric_Pad1.18x1.45mm_HandSolder
C4, C5, C6, C7: 1n; C_0805_2012Metric_Pad1.18x1.45mm_HandSolder
C8: 10n; C_0805_2012Metric_Pad1.18x1.45mm_HandSolder
C9: 47n; C_0805_2012Metric_Pad1.18x1.45mm_HandSolder
C10: 2.2n; C_0805_2012Metric_Pad1.18x1.45mm_HandSolder
C11, C14: 2.2u; C_0805_2012Metric_Pad1.18x1.45mm_HandSolder
C15: 4.7u; CP_Radial_D8.0mm_P3.80mm
C16: 100n; C_0805_2012Metric_Pad1.18x1.45mm_HandSolder
Crystal1: 4Mhz; Crystal_HC18-U_Vertical
D1, D2: 1N4007; D_DO-41_SOD81_P10.16mm_Horizontal
D3: 4.7V; D_DO-41_SOD81_P10.16mm_Horizontal
D5: 12V; D_DO-41_SOD81_P10.16mm_Horizontal
D7: Q_SCR_KGA; TO-92_Wide
D8: Q_SCR_KGA; TO-92L_Wide
H1, H2, H3, H4: MountingHole; MountingHole_3.2mm_M3
J1: SCL_GND_SCA; PinHeader_1x03_P2.54mm_Vertical
J2: Fuente5V; PinHeader_1x02_P2.54mm_Vertical
J4: Fuente12V; PinHeader_1x02_P2.54mm_Vertical
J5: CONSMA006.062-G; TE_CONSMA006.062-G; PARTREV B
JP1: Jumper_2_Bridged; PinHeader_1x02_P2.54mm_Vertical
Q1: BCW31_; SOT23-BEC
R1: 68; R_0805_2012Metric_Pad1.20x1.40mm_HandSolder
R2: 33; R_0805_2012Metric_Pad1.20x1.40mm_HandSolder
R3: 7.5k; R_0805_2012Metric_Pad1.20x1.40mm_HandSolder
R4: 22k; R_0805_2012Metric_Pad1.20x1.40mm_HandSolder
R5: 1K; R_0805_2012Metric_Pad1.20x1.40mm_HandSolder
R6, R7: 100; R_Axial_DIN0207_L6.3mm_D2.5mm_P10.16mm_Horizontal
SP1: SOP-16_4.4x10.4mm_P1.27mm
U1: QFN50P500X500X100-33N

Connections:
+5V: C3.1, C4.1, C11.2, C12.2, C13.1, C14.1, D2.1 (K), D3.1 (K), D7.3 (A), J2.1, SP1.12 (Vcc), U1.6 (VCC(Dig)), U1.21 (VCC(RF))
+12V: C15.1, C16.1, D1.1 (K), D5.1 (K), D8.3 (A), J4.1, R4.2
GND: C1.1, C3.2, C4.2, C6.1, C10.2, C11.1, C12.1, C13.2, C14.2, C15.2, C16.2, C17.2, C18.2, Crystal1.2, D1.2 (A), D2.2 (A), D7.1 (K), D8.1 (K), J1.2, J2.2, J4.2, J5.2, J5.3, J5.4, J5.5, JP1.1 (A), Q1.E, R1.2, R6.2, R7.2, SP1.15 (VEE), U1.33 (GND)
unnamed: C5.1, R2.1
unnamed: C5.2, SP1.14 (RF_Input)
unnamed: C6.2, SP1.13 (RF_Input)
unnamed: C7.2, R1.1, R2.2
unnamed: C8.1, Q1.C, R3.2, R4.1, R5.2
unnamed: C8.2, C9.1, R3.1
unnamed: D3.2 (A), D7.2 (G), R7.1
unnamed: D5.2 (A), D8.2 (G), R6.1
unnamed: C17.1, J1.1, SP1.4 (SDA)
unnamed: C18.1, J1.3, SP1.5 (SCL)
unnamed: JP1.2 (B), SP1.6 (Port_P3)
unnamed: C9.2, SP1.1 (Charge_Pump)
unnamed: C2.2, Crystal1.1, SP1.3 (Crystal)
unnamed: C1.2, C2.1, SP1.2 (Crystal_Cap)
unnamed: Q1.B, SP1.16 (Drive)
unnamed: J5.1, U1.19 (RFOUT)
unnamed: C7.1, U1.4 (RFOUT/4)
unnamed: C10.1, R5.1, U1.29 (VTUNE)

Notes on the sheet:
Crowbar Protección 5V Sintetizador
Crowbar Protección 12V Sintetizador

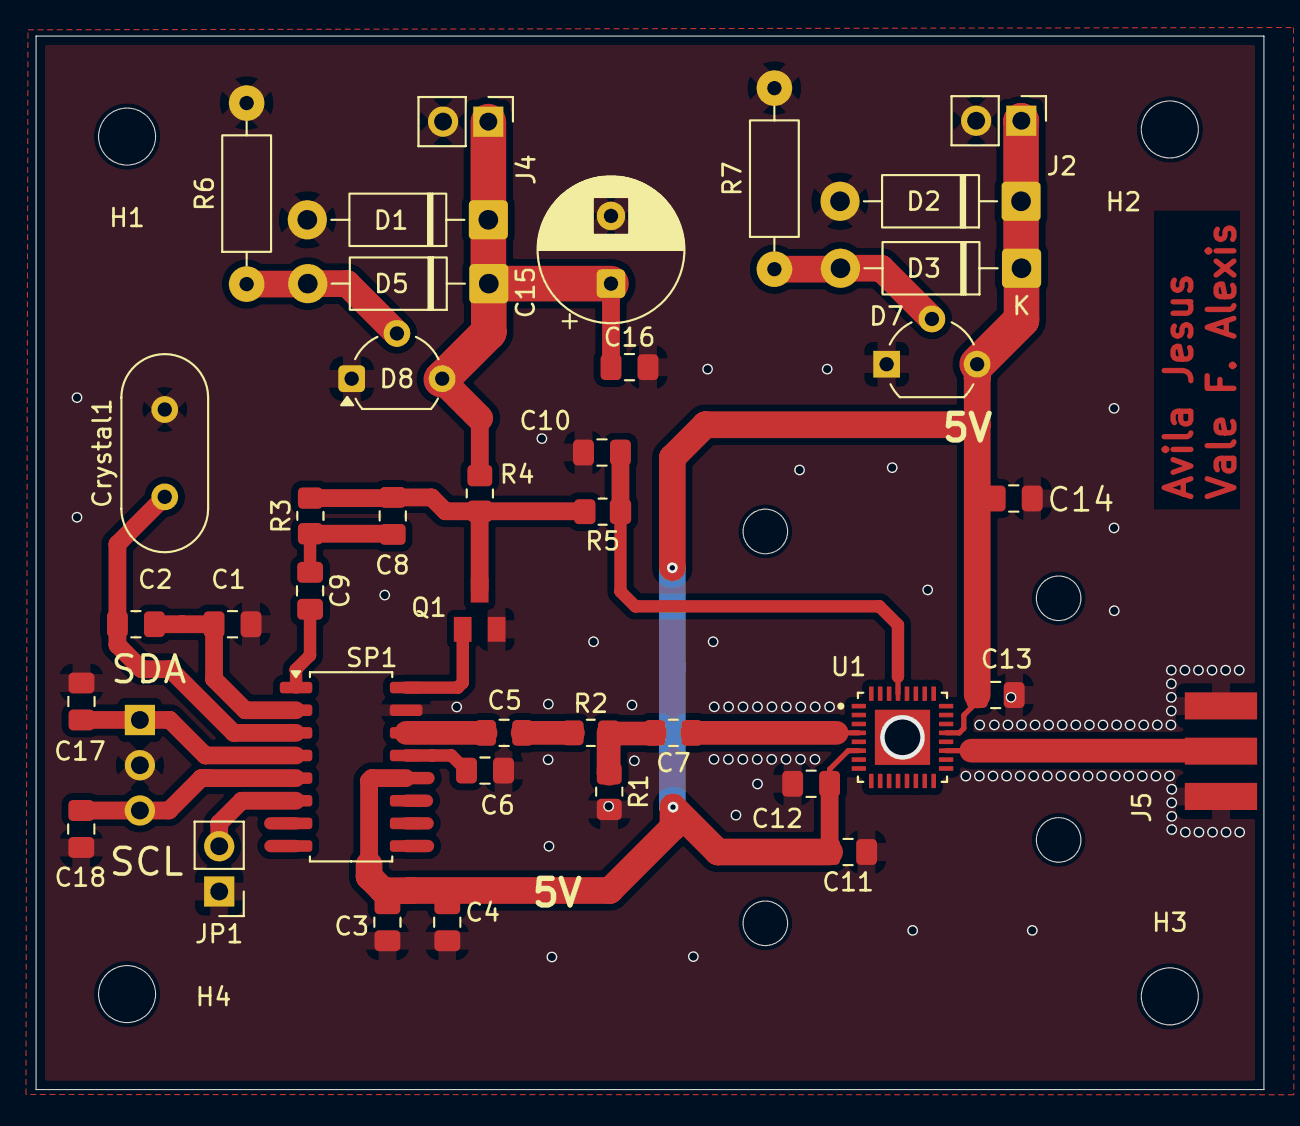
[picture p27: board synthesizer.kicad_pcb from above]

Board: 2 copper layers, 68.9 x 59.1 mm, 48 parts (1 on the bottom side), 21 nets.

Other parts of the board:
H5, H5#2, H5#3, H5#4: MountingHole; MountingHole_2.5mm

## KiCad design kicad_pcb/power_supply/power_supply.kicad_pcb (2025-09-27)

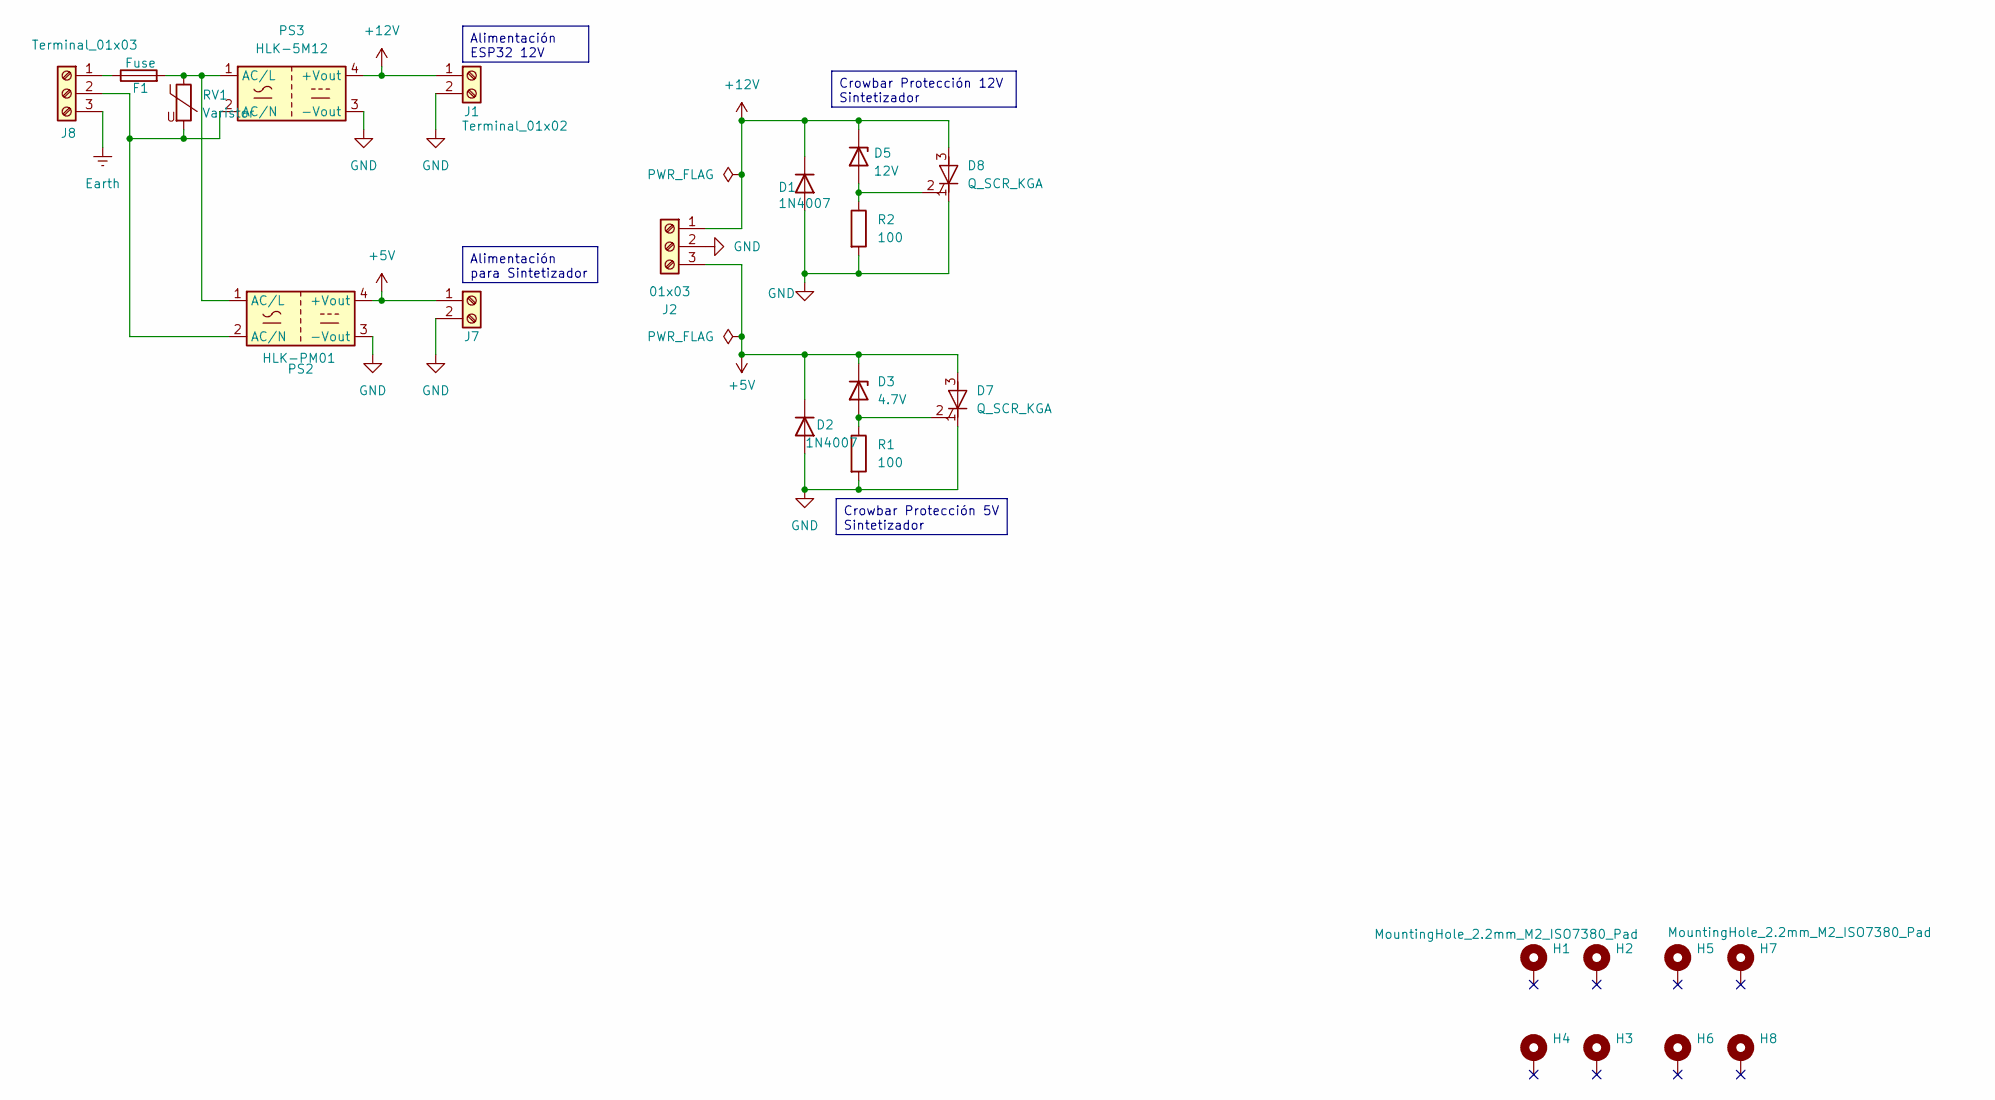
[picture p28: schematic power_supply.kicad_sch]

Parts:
D1, D2: 1N4007; D_DO-41_SOD81_P10.16mm_Horizontal
D3: 4.7V; D_DO-41_SOD81_P10.16mm_Horizontal
D5: 12V; D_DO-41_SOD81_P10.16mm_Horizontal
D7: Q_SCR_KGA; TO-92_Wide
D8: Q_SCR_KGA; TO-92L_Wide
F1: Fuse; Fuseholder_Cylinder-5x20mm_Schurter_0031_8201_Horizontal_Op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
H1, H2, H3, H4, H5, H6, H7, H8: MountingHole_2.2mm_M2_ISO7380_Pad
J1, J7: Terminal_01x02; TerminalBlock_MetzConnect_Type011_RT05502HBLC_1x02_P5.00mm_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
J2: 01x03; TerminalBlock_MaiXu_MX126-5.0-03P_1x03_P5.00mm
J8: Terminal_01x03; TerminalBlock_MaiXu_MX126-5.0-03P_1x03_P5.00mm
PS2: HLK-PM01; Converter_ACDC_Hi-Link_HLK-PMxx
PS3: HLK-5M12; Converter_ACDC_Hi-Link_HLK-5Mxx
R1, R2: 100; R_Axial_DIN0207_L6.3mm_D2.5mm_P10.16mm_Horizontal
RV1: Varistor; RV_Disc_D12mm_W4.2mm_P7.5mm

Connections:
+5V: D2.1 (K), D3.1 (K), D7.3 (A), J2.3, J7.1, PS2.4 (+Vout)
+12V: D1.1 (K), D5.1 (K), D8.3 (A), J1.1, J2.1, PS3.4 (+Vout)
Earth: J8.3
GND: D1.2 (A), D2.2 (A), D7.1 (K), D8.1 (K), J1.2, J2.2, J7.2, PS2.3 (-Vout), PS3.3 (-Vout), R1.2, R2.2
unnamed: D3.2 (A), D7.2 (G), R1.1
unnamed: D5.2 (A), D8.2 (G), R2.1
unnamed: F1.1, J8.1
unnamed: J8.2, PS2.2 (AC/N), PS3.2 (AC/N), RV1.2
unnamed: F1.2, PS2.1 (AC/L), PS3.1 (AC/L), RV1.1

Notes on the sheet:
Crowbar Protección 5V Sintetizador
Alimentación para Sintetizador
Crowbar Protección 12V Sintetizador
Alimentación ESP32 12V

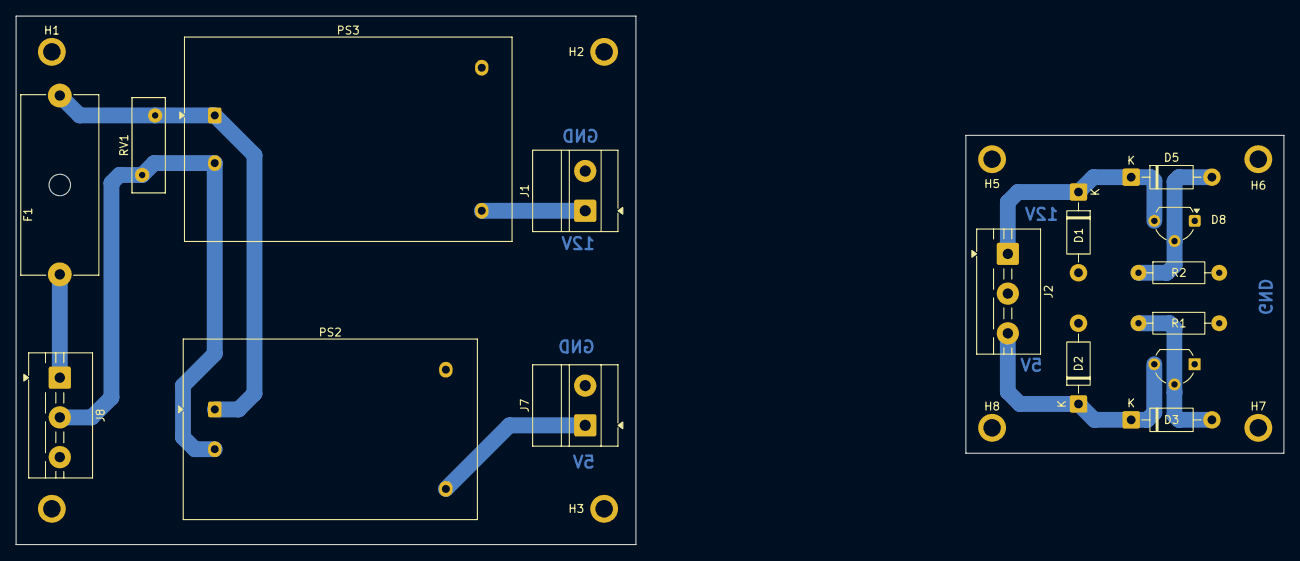
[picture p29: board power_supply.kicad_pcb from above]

Board: 2 copper layers, 159.5 x 66.5 mm, 24 parts (1 on the bottom side), 8 nets.

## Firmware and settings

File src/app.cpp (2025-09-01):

#include "comandos.h"
#include "driver/i2c.h"
#include "interfaz.h"
#include "sintetizador.h"
#include "teclado.h"
#include "ticker.h"
#include <Arduino.h>
#include <BluetoothSerial.h>
#include <LiquidCrystal.h>
#include <Wire.h>

#define botones 1

BluetoothSerial SerialBT;
void SintetizadorInicializa();
void enviari2c(uint8_t);
extern "C" {
static void UART_write_string(const char *str)
{
    SerialBT.print(str);
}
static void UART_write_numero(int num)
{
    SerialBT.print(num);
}
static void UART_write(int c)
{
    SerialBT.write(static_cast<uint8_t>(c));
}
}
void vTareaPeriodica(void *pvParameters)
{
    TickType_t xLastWakeTime;
    xLastWakeTime        = xTaskGetTickCount();
    static int tiempo_ms = 100;
    while (1) {
        tiempo_ms = SintetizadorTick();                            // Llama a la función que actualiza el sintetizador
        vTaskDelayUntil(&xLastWakeTime, pdMS_TO_TICKS(tiempo_ms)); // Espera el tiempo retornado por SintetizadorTick
    }
}
// const int rs= D1, en=D2, d4= D4, d5=D5, d6=D6, d7=D7;
const int rs = D7, en = D6, d4 = D5, d5 = D4, d6 = D2, d7 = D1;
LiquidCrystal lcd(rs, en, d4, d5, d6, d7); // Instancia LCD

int mostrarTecla = 0;

void vtareaMostrarFrecuencia(void *pvParameters)
{
    static int borrar, contadorBorrar = 0;
    static char buffer[17]; // 16 + null
    int frecuencia = sintetizadorFrecuencia();
    int estado     = sintetizadorEstado();
    for (;;) {
        if (contadorBorrar++ > 3) {
            contadorBorrar = 0;
            borrar         = !borrar;
        }
        frecuencia = sintetizadorFrecuencia();
        estado     = sintetizadorEstado();
        lcd.clear();
        lcd.setCursor(0, 0);
        snprintf(buffer, sizeof(buffer), "Frec: %d MHz", frecuencia);
        lcd.print(buffer);
        if (borrar && sintetizadorEdicion()) {
            lcd.setCursor(11 - sintetizadorEdicion(), 0);
            lcd.print(" ");
        }
        lcd.setCursor(0, 1);
        if (estado) {
            lcd.print("Enclavado!");
        } else {
            lcd.print("No enclavado");
        }
        // lcd.print(mostrarTecla);
        // lcd.print(sintetizadorEdicion());
        // if (borrar) lcd.print("X");
        vTaskDelay(pdMS_TO_TICKS(200)); // Actualiza cada 1 segundo
    }
}

void vtareaComandosTeclado(void *pvParameters)
{
    EventGroupHandle_t eventGroup = static_cast<EventGroupHandle_t>(pvParameters);
    EventBits_t uxBits;
    for (;;) {
        // Espera por gestos de teclado (KEV_...)
        uxBits = xEventGroupWaitBits(eventGroup, KEV_ALL_DOWN | KEV_ALL_UP, pdTRUE, pdFALSE, portMAX_DELAY);

        if (uxBits & KEV_SELECT_DOWN) {
            sintetizadorTeclado(SELECT_KEY);
            mostrarTecla = SELECT_KEY;
        } else if (uxBits & KEV_LEFT_DOWN) {
            sintetizadorTeclado(LEFT_KEY);
            mostrarTecla = LEFT_KEY;
        } else if (uxBits & KEV_DOWN_DOWN) {
            sintetizadorTeclado(DOWN_KEY);
            mostrarTecla = DOWN_KEY;
        } else if (uxBits & KEV_UP_DOWN) {
            sintetizadorTeclado(UP_KEY);
            mostrarTecla = UP_KEY;
        } else if (uxBits & KEV_RIGHT_DOWN) {
            sintetizadorTeclado(RIGHT_KEY);
            mostrarTecla = RIGHT_KEY;
        } else {
            mostrarTecla = 0;
        }
    }
}

TaskHandle_t tareaPeriodicaHandle = NULL;
TecladoTaskParams tecladoConfig;
EventGroupHandle_t eventGroup;
void setup()
{
    pinMode(12, OUTPUT); // Configura el pin 2 como salida para el LED
    pinMode(13, OUTPUT); // Configura el pin 2 como salida para el LED
    digitalWrite(12, LOW);
    digitalWrite(13, LOW);
    pinMode(A0, INPUT); // Configura el pin 2
    static const UART uart = {
        .write_string = UART_write_string, .write_numero = UART_write_numero, .write = UART_write};
    static const I2C i2c = {.write_freq        = SintetizadorCambiaFrecuencia,
                            .read_state        = estadoDelSintetizador,
                            .write_mode        = SintetizadorCambiaModo,
                            .configurarBarrido = configurarBarrido,
                            .paraBarrido       = paraBarrido};

    // Inicia la comunicación serial para depuración
    Serial.begin(9600);
    // Inicia la comunicación Bluetooth
    SerialBT.begin("Sintetizador de Banda Ku"); // Nombre del dispositivo Bluetooth
    // Inicia la comunicación I2C
    Wire.begin();
    Wire.setClock(400000); // 400 kHz
    // Configuración inicial del sintetizador (ejemplo)
    SintetizadorInicializa();
    lcd.begin(16, 2);
    Comandos_init(&uart);
    comandos_i2c(&i2c);
    if (xTaskCreate(vTareaPeriodica, "TareaPeriodica", 4096, NULL, 3, &tareaPeriodicaHandle) != pdPASS) {
        digitalWrite(2, HIGH);
    }

    xTaskCreatePinnedToCore(vtareaMostrarFrecuencia,         // función de la tarea
                            "TareaMostrarFrec",              // nombre
                            configMINIMAL_STACK_SIZE + 1000, // stack
                            NULL,                            // parámetros
                            2,                               // prioridad
                            NULL,                            // handle
                            1                                // core (opcional, ESP32)
    );

    eventGroup = xEventGroupCreate();
    while (!eventGroup)
        digitalWrite(12, HIGH);
    tecladoConfig = {eventGroup, 25, A0};

    xTaskCreatePinnedToCore(vtareaComandosTeclado,          // función de la tarea
                            "DetectarTeclas",               // nombre
                            TECLADO_TASK_STACK_SIZE + 1000, // stack
                            eventGroup,                     // parámetros
                            1,                              // prioridad
                            NULL,                           // handle
                            1                               // core (opcional, ESP32)
    );

    if (xTaskCreatePinnedToCore(tecladoTask,                    // función de la tarea
                                "TareaTeclado",                 // nombre
                                TECLADO_TASK_STACK_SIZE + 1024, // stack
                                &tecladoConfig,                 // parámetros
                                2,                              // prioridad
                                NULL,                           // handle
                                1                               // core (opcional, ESP32)
                                ) == pdPASS)
    {
        // digitalWrite(2, LOW); // Enciende el LED si la tarea no se creó correctamente
    }
    digitalWrite(12, LOW);
}

char caracter_recibido;
void loop()
{ // Codigo para lectura en consola.
    if (SerialBT.available()) {
        caracter_recibido = SerialBT.read();
        Serial.print(caracter_recibido);
        if (Comandos_procesa(static_cast<char>(caracter_recibido))) {
        }
    }
}

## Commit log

2024-08-28 Errores de com
2024-08-29 Corregida direccion i2c
2024-10-23 Cambio de valor de R
2024-10-30 agregados msj de test
2025-05-10 Configuración de clangformat. Documentación en buffer
2025-06-18 Cambios para Tarea
2025-06-24 limpieza de codigo sint
2025-06-24 Corregido problema de lock
    [app.cpp]
2025-09-27 Agregado Esquema fuente
    [power_supply.kicad_pcb, power_supply.kicad_sch]
2025-09-27 Se agrega esquema y pcb de sintetizador
    [synthesizer.kicad_pcb, synthesizer.kicad_sch]
2025-10-01 Agregada LineaPCB
    [synthesizer.kicad_pcb]
2025-10-02 modificación de pcb y esquema
    [synthesizer.kicad_pcb, synthesizer.kicad_sch]
2025-10-08 Agregadas vias (sin check)
    [synthesizer.kicad_pcb]
2025-10-14 Simulacion pcb
    [synthesizer.kicad_pcb]
2025-10-14 cambio de huella y posiciones de elemenntos. se reduce el tamaño de placa
    [synthesizer.kicad_pcb, synthesizer.kicad_sch]
2025-10-14 Se agregan caps para sda y scl
    [synthesizer.kicad_pcb, synthesizer.kicad_sch]
2025-10-14 Cambio de huella R4
    [synthesizer.kicad_pcb, synthesizer.kicad_sch]
2025-10-15 Lineas SDA/SCL
    [synthesizer.kicad_pcb]
2025-10-15 Se modificaron los tamaños de los elementos smd a 0805 y se modificaron anchos de pistas
    [synthesizer.kicad_pcb, synthesizer.kicad_sch]
2025-10-20 carpeta out
    [CalculoPasosPorDivison.xlsx, synthesizer.kicad_pcb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]
2026-03-28 Se modifica placa para nuevo integrado
    [synthesizer.kicad_pcb, synthesizer.kicad_sch]
2026-04-27 Consulta estado contínuamente y no solo la primera vez
